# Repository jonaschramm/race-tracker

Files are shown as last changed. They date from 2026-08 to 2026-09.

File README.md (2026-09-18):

<p align="center">
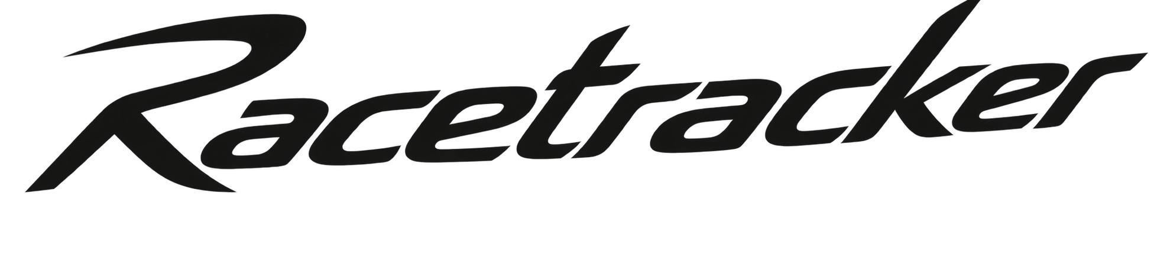
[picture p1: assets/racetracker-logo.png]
RaceTracker
  
</p>

Custom PCB data logger for motorcycle racing: GPS position + IMU motion data,
logged to a microSD card, with an e-Paper status display. Built around an
ESP32-S3 (WiFi/BT built in) so it can also stream/sync over WiFi.

## Current version: V3 (ESP32-S3)

**This is the active, current board.** Everything else in this repo (see
[History / older versions](#history--older-versions) below) is superseded —
kept for reference only, not under active development.

```
RaceTracker.kicad_prj/V3 ESP32/RaceTracker_v3/RaceTracker_v3.kicad_pro
```

Open that project file in KiCad (10.0.5 or newer) — schematic
(`RaceTracker_v3.kicad_sch`) and PCB (`RaceTracker_v3.kicad_pcb`) are
alongside it.

### Status

- Schematic: ERC clean (0 violations).
- PCB: fully routed by hand, `kicad-cli pcb drc --severity-all` → 0 errors
  (a handful of expected warnings only — see below).
- Board: 4-layer, ~56×66mm with rounded corner bosses for 4× M2 mounting
  holes.
- BOM: all 44 parts have a manufacturer part number and LCSC code (or
  DigiKey, where LCSC doesn't carry the part) in the schematic symbol
  properties — see `bom/bom.csv`.

**Known, expected DRC warnings (not bugs):**
- `lib_footprint_mismatch` on J1, J5, J6, SW1, U1 — these footprints were
  deliberately hand-adjusted to match real component pad geometry (pulled
  from the parts' own datasheets/reference designs) rather than the stock
  KiCad library footprint. **Do not run "Update Footprint from Library" on
  these** — it would silently overwrite the verified geometry.

### Key components

| Function | Part |
|---|---|
| MCU (WiFi + BT) | ESP32-S3-WROOM-1-N8 (U1) |
| IMU (6-axis) | Würth WSEN-ISDS (U4) |
| GPS | external module via J3 (2.54mm header, I2C) — no onboard GPS |
| Storage | microSD (J4) |
| Display | e-Paper via J6 (8-pin header) |
| Charging | MCP73831 Li-Ion charger (U2) + USB-C (J1) |
| 3.3V rail | AP2112K-3.3 LDO (U3) |
| Debug | UART via J5 (4-pin header) |

Pin-header connectors (J3, J5, J6) have their pin functions silkscreened
next to each pin so nothing gets miswired when the board is in hand without
the schematic open.

### 3D preview

<p align="center">
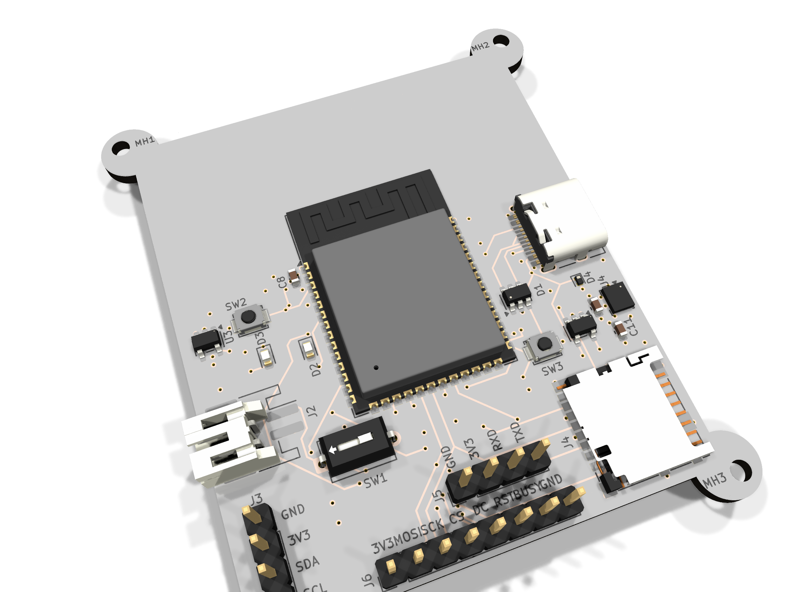
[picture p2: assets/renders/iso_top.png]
RaceTracker V3 - component side
  
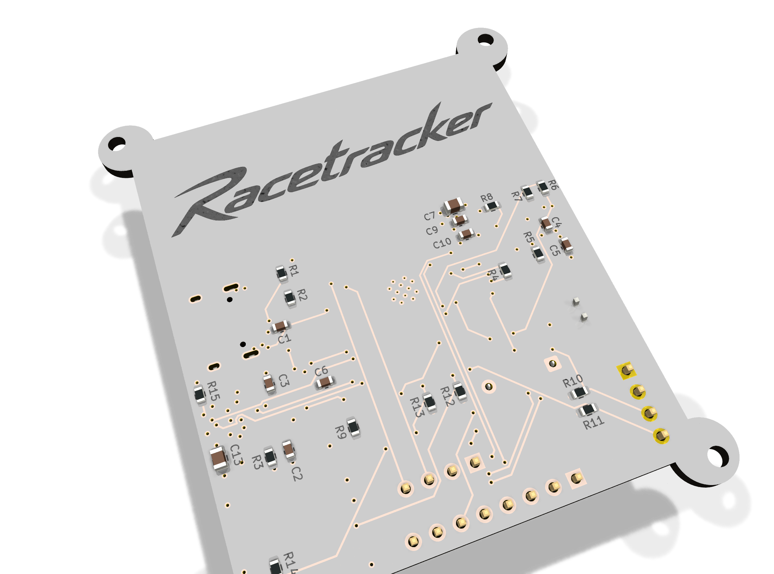
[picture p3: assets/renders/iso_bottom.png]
RaceTracker V3 - logo side
  
</p>

Rendered straight from the board file (`kicad-cli pcb render`). A ready-to-embed,
interactive 3D model (quantized GLB, 3.4 MB — Draco was tried first but needs an
external decoder that not every embedding context can reach) lives at
[`RaceTracker.kicad_prj/V3 ESP32/RaceTracker_v3/3d/RaceTracker_v3.glb`](RaceTracker.kicad_prj/V3%20ESP32/RaceTracker_v3/3d/RaceTracker_v3.glb) —
drop it into a [`<model-viewer>`](https://modelviewer.dev/) tag on any webpage to let
visitors spin the board around (also works in AR on phones). More stills in
`assets/renders/`.

### Open items

Not yet done — flagging so nothing is assumed finished:

1. **RF review** — the ESP32-S3's on-board antenna keepout is respected on
   the PCB, but nobody with hands-on RF experience has reviewed the
   placement. Espressif's own guideline calls for **≥15mm clearance between
   the antenna and any metal** (enclosure, shielding) — the two mounting
   holes closest to the antenna (top-left/top-right) are only ~3mm away, so
   **use nylon/plastic M2 screws there**, not metal.
2. **Enclosure / mechanical design** — no current mechanical spec for a
   case; board dimensions have changed several times, don't reuse an old one.
3. **3D models / "finished" 3D view** — not started.
4. Two BOM values are assumptions, not confirmed: D2/D3 LED colors (set to
   red/green — schematic didn't specify a color) and SW1's exact MPN
   (couldn't verify its physical dimensions against the datasheet).
5. 27 pads show as "no net" against the schematic's auto-generated
   placeholder nets — reviewed at a glance as genuinely-unused pins
   (GPIO headroom, USB SBU lines), not individually re-verified.

## Repo layout

```
RaceTracker.kicad_prj/
├── *.kicad_sch, RaceTracker.kicad_pcb   ← V1 (SAMD21 + onboard GPS/WiFi modules) — historical
├── V3 ESP32/RaceTracker_v3/             ← V3 (ESP32-S3) — CURRENT, see above
└── V3 ESP32/tools/                      ← pcbnew scripting helpers used while building V3
v2-simple/                                ← V2 (SAMD21, simplified, external GPS/WiFi) — abandoned mid-layout, superseded by V3
reference/eagle/                          ← imported Eagle symbols (Arduino MKR WiFi 1010) used as a source for V1/V2 parts
bom/bom.csv                               ← current BOM with MPN/LCSC/pricing data (V3)
```

### History / older versions

- **V1** (`RaceTracker.kicad_prj/*.kicad_sch` at the repo root, tag
  `v1-full`): original design — Arduino MKR WiFi 1010 (SAMD21) + separate
  u-blox ZED-F9P RTK GPS module + MPU-6050 IMU. Fully routed, but heavier
  and pricier than needed for the actual use case.
- **V2 / `v2-simple`**: a pivot to drop the onboard GPS/WiFi modules in
  favor of external pluggable headers, still on the SAMD21. Placement-only;
  routing was never finished before the project moved to V3's ESP32-S3
  (which has WiFi/BT built in, removing the need for a separate radio
  module entirely). Kept for reference; not maintained.

## Branches

`main` tracks the current state (V3). Historical exploration happened on
`v2-simple` — merged into `main` and not separately maintained going forward.

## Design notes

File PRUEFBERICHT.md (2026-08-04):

# Prüfbericht zur Handvalidierung — Race Tracker Platine

Erzeugt aus denselben Daten wie die Schaltpläne. Zweck: du kannst jede Verbindung gegen die
Original-Referenzschaltpläne (Arduino MKR WiFi 1010 / SparkFun GPS-RTK-SMA) abhaken,
ohne die KiCad-Datei lesen zu müssen.

**So prüfst du:** Für jedes Netz unten steht, welche Bauteil-Pins zusammenhängen.
Die Spalte *Quelle* sagt, ob das exakt so im Referenz-Schaltplan steht.

## Blatt: Power

Bauteile auf diesem Blatt: **40**, Netze: **30**

| Netz | verbundene Bauteil-Pins | Quelle |
|---|---|---|
| `+3V3` | R24.1, R26.1, U6.OUT | identisch |
| `+3V3D` | U3.OUT, C8.1, C9.2, C33.1 | identisch |
| `+3V8` | U5.SYS, L2.2, C19.1, C20.1, C22.1, C32.1, R23.2, U3.EN, U3.IN, U6.EN, U6.IN | identisch |
| `+5V` | D1.4, F1.2, Q2.D, D3.C | identisch |
| `BATT_RAW` | J7.1, F2.1 | = `N$3` |
| `CC1` | R37.1 ⚠️ **nur 1 Anschluss** | manuell (Neuentwurf, s.u.) |
| `CC2` | R38.1 ⚠️ **nur 1 Anschluss** | manuell (Neuentwurf, s.u.) |
| `CHG_BOOT` | U5.BTST, C15.1 | = `N$18` |
| `CHG_CE` | U5.CE, R25.2 | = `N$24` |
| `CHG_ILIM` | U5.ILIM, R28.1 | = `N$19` |
| `CHG_OTG` | U5.OTG, R26.2, Q3.D | = `N$22` |
| `CHG_REGN` | U5.REGN, C16.1, R30.1 | = `N$21` |
| `CHG_SW` | U5.SW, L2.1, C15.2 | = `N$15` |
| `CHG_TS` | U5.TS1, U5.TS2, R29.2, R30.2 | = `N$23` |
| `CHG_VBUS` | Q2.S, Q2.C, R27.2, U5.VBUS, C14.1 | = `N$17` |
| `DL2_ANODE` | R23.1, DL2.A | = `N17798864` |
| `DL3_ANODE` | R27.1, DL3.A | = `N17834267` |
| `GND` | R37.2, R38.2, R1.1, C1.2, J7.2, J7.SH, D2.A, DL3.C, U5.PGND, U5.TH, C12.2, C13.2, C14.2, C16.2, C19.2, C20.2, C22.2, C32.2, R28.2, R29.1, R25.1, R1… | manuell (Neuentwurf, s.u.) |
| `I2C_SCL` | U5.SCL ⚠️ **nur 1 Anschluss** | = `PA09_S0_I2C_SCL` |
| `I2C_SDA` | U5.SDA ⚠️ **nur 1 Anschluss** | = `PA08_S0_I2C_SDA` |
| `PA18_OTG` | Q3.G ⚠️ **nur 1 Anschluss** | identisch |
| `PMICINT` | U5.INT, R24.2 | identisch |
| `STAT` | U5.STAT, DL2.C | identisch |
| `USB_N` | D1.3 ⚠️ **nur 1 Anschluss** | identisch |
| `USB_P` | D1.2 ⚠️ **nur 1 Anschluss** | identisch |
| `USB_SHIELD_RC` | D1.1, R1.2, C1.1 | = `N$1` |
| `VBAT` | F2.2, D2.C, U5.BAT | = `VBATT` |
| `VBUS_RAW` | F1.1 ⚠️ **nur 1 Anschluss** | = `N$2` |
| `VIN` | Q2.G, Q2.A, R19.2 | identisch |
| `VUSB1` | D3.A, U5.PMID, C12.1, C13.1 | identisch |

**Netze mit nur einem Anschluss auf Power** (8): `CC1`, `CC2`, `I2C_SCL`, `I2C_SDA`, `PA18_OTG`, `USB_N`, `USB_P`, `VBUS_RAW`

Das sind ungenutzte Pins (im Original gingen sie nur zu Steckverbindern, die wir weggelassen haben).
Sie sind **kein Fehler**, aber die ERC wird sie als „nicht verbunden“ melden — dort kannst du sie
mit einem No-Connect-Kreuz quittieren oder für spätere Erweiterungen offenlassen.

## Blatt: MCU_Radio

Bauteile auf diesem Blatt: **46**, Netze: **64**

| Netz | verbundene Bauteil-Pins | Quelle |
|---|---|---|
| `+3V3` | U1.VDDIN, U1.VDDIO@1, U1.VDDIO@2, C17.1, C18.1, C21.1, C24.1, C26.1, L3.1, R5.2, R21.1, R13.2, R14.2, R4.2, R15.1 | identisch |
| `+3V3D` | U2.VCC, U2.VCCIO, R7.2 | identisch |
| `DL1_ANODE` | R15.2, DL1.A | = `N$7` |
| `DL1_KATHODE` | Q1.D, DL1.C | = `N$10` |
| `EPD_BUSY` | U1.PA02 ⚠️ **nur 1 Anschluss** | = `PA02_AIN0` |
| `EPD_CS` | U1.PA06 ⚠️ **nur 1 Anschluss** | = `PA06_AIN6` |
| `EPD_DC` | U1.PA05 ⚠️ **nur 1 Anschluss** | = `PA05_AIN5` |
| `EPD_RST` | U1.PA04 ⚠️ **nur 1 Anschluss** | = `PA04_AIN4` |
| `GND` | U1.EP, U1.GND@1, U1.GND@2, U1.GND@3, U1.GNDANA, C17.2, C18.2, C21.2, C24.2, C26.2, C25.2, C23.2, C27.2, C5.2, C7.2, C6.2, R9.1, C3.1, C4.1, PB1.1, … | identisch |
| `I2C_SCL` | U1.PA09, R20.2, R13.1 | = `PA09_S0_I2C_SCL` |
| `I2C_SDA` | U1.PA08, R18.2, R14.1 | = `PA08_S0_I2C_SDA` |
| `IMU_INT` | U1.PB10 ⚠️ **nur 1 Anschluss** | = `PB10_TCC0-W4` |
| `LED_BLUE` | U2.RMII_RXD1/DAC17/GPIO26, DL4.RED_A | identisch |
| `LED_ERR` | U1.PA23 ⚠️ **nur 1 Anschluss** | = `PA23_TC4-W1` |
| `LED_FIX` | U1.PA21 ⚠️ **nur 1 Anschluss** | = `PA21_TCC0-W7` |
| `LED_GREEN` | U2.RMII_RXD0/DAC16/GPIO25, DL4.GREEN_A | identisch |
| `LED_REC` | U1.PA22 ⚠️ **nur 1 Anschluss** | = `PA22_TC4-W0` |
| `LED_RED` | U2.RMII_CRSDV/GPIO27, DL4.BLUE_A | identisch |
| `NINA_GPIO13` | U2.JTCLK/GPIO13, R18.1 | = `N$11` |
| `NINA_GPIO14` | U2.JTMS/GPIO14, R20.1 | = `N$12` |
| `NINA_GPIO15` | U2.JTDO/GPIO15, R22.2 | = `N$26` |
| `NINA_GPIO21` | U2.SPIV_HD/RMII_TXEN/GPIO21, R12.2 | = `N$27` |
| `NINA_GPIO4` | U2.RMII_MDIO/GPIO4, R17.1 | = `N$13` |
| `NINA_LPO` | U2.LPO_IN/GPIO32 ⚠️ **nur 1 Anschluss** | = `N$25` |
| `NINA_RESET_N` | U2.RESET_N, R7.1, Q5.D | = `N$9` |
| `NINA_SELFRST` | R11.1, R17.2, Q5.G | = `N$28` |
| `PA00_XIN32` | U1.PA00/XIN32, Y1.2, C3.2 | identisch |
| `PA01_XOUT32` | U1.PA01/XOUT32, Y1.1, C4.2 | identisch |
| `PA03_VREFA` | U1.PA03, C5.1, C7.1 | identisch |
| `PA10_TCC0-W2` | U1.PA10 ⚠️ **nur 1 Anschluss** | identisch |
| `PA11_TCC0-W3` | U1.PA11 ⚠️ **nur 1 Anschluss** | identisch |
| `PA12_S2_TX/MOSI` | U1.PA12, U2.GPIO12 | identisch |
| `PA13_S2_RX/MISO` | U1.PA13, U2.SPIV_DI/GPIO23 | identisch |
| `PA14_S2_RTS/CS` | U1.PA14, U2.SPIV_CS/GPIO5, U2.UART_CTS/RMII_TXD0/SPIV_D0/GPIO19 | identisch |
| `PA15_S2_CTS/SCK` | U1.PA15, U2.SPIV_CLK/GPIO18, U2.UART_RTS/RMII_TXD1/SPIV_WP/GPIO22 | identisch |
| `PA18_OTG` | U1.PA18, R21.2 | identisch |
| `PA20_TCC0-W6` | U1.PA20, R16.2, Q1.G | identisch |
| `PA27_GPIO0` | U1.PA27, U2.RMII_CLK/GPIO0 | identisch |
| `PA28_ACK` | U1.PA28, U2.GPIO33 | identisch |
| `PA30_SWCLK` | U1.PA30/SWCLK, R4.1, R12.1 | identisch |
| `PA31_SWDIO` | U1.PA31/SWDIO, R22.1 | identisch |
| `PB02_AIN10` | U1.PB02 ⚠️ **nur 1 Anschluss** | identisch |
| `PB03_AIN11` | U1.PB03 ⚠️ **nur 1 Anschluss** | identisch |
| `PB08_RST` | U1.PB08, R10.1, Q5.G | identisch |
| `PB09_FILT` | U1.PB09, C6.1, R8.1, R9.2 | = `N$6` |
| `PB22_S5_TX` | U1.PB22, U2.UART_RXD/GPIO3 | identisch |
| `PB23_S5_RX` | U1.PB23, U2.UART_TXD/GPIO1 | identisch |
| `RESET#` | R6.2, Q5.D | identisch |
| `RESETN` | U1.RESETN, R2.2, R3.2, R6.1, R5.1, C2.1 | identisch |
| `RESETN_TP` | R2.1 ⚠️ **nur 1 Anschluss** | = `N$4` |
| `RESET_BTN` | PB1.2, R3.1 | = `N17658775` |
| `RGB_KATH1` | DL4.RED_C, R34.2 | = `N$14` |
| `RGB_KATH2` | DL4.GREEN_C, R35.2 | = `N$16` |
| `RGB_KATH3` | DL4.BLUE_C, R36.2 | = `N$20` |
| `SD_CD` | U1.PB11 ⚠️ **nur 1 Anschluss** | = `PB11_TCC0-W5` |
| `SD_CS` | U1.PA07 ⚠️ **nur 1 Anschluss** | = `PA07_AIN7` |
| `SPI_MISO` | U1.PA19 ⚠️ **nur 1 Anschluss** | = `PA19_S1_MISO` |
| `SPI_MOSI` | U1.PA16 ⚠️ **nur 1 Anschluss** | = `PA16_S1_MOSI` |
| `SPI_SCK` | U1.PA17 ⚠️ **nur 1 Anschluss** | = `PA17_S1_SCK` |
| `USB_N` | U1.PA24/USB_DM ⚠️ **nur 1 Anschluss** | identisch |
| `USB_P` | U1.PA25/USB_DP ⚠️ **nur 1 Anschluss** | identisch |
| `VBAT` | R8.2 | = `VBATT` |
| `VDDANA_FILT` | U1.VDDANA, L3.2, C23.1, C27.1 | = `N17852357` |
| `VDDCORE_DEC` | U1.VDDCORE, C25.1 | = `N17852431` |

**Netze mit nur einem Anschluss auf MCU_Radio** (21): `EPD_BUSY`, `EPD_CS`, `EPD_DC`, `EPD_RST`, `IMU_INT`, `LED_ERR`, `LED_FIX`, `LED_REC`, `NINA_LPO`, `PA10_TCC0-W2`, `PA11_TCC0-W3`, `PB02_AIN10`, `PB03_AIN11`, `RESETN_TP`, `SD_CD`, `SD_CS`, `SPI_MISO`, `SPI_MOSI`, `SPI_SCK`, `USB_N`, `USB_P`

Das sind ungenutzte Pins (im Original gingen sie nur zu Steckverbindern, die wir weggelassen haben).
Sie sind **kein Fehler**, aber die ERC wird sie als „nicht verbunden“ melden — dort kannst du sie
mit einem No-Connect-Kreuz quittieren oder für spätere Erweiterungen offenlassen.

## Blatt: GPS

Bauteile auf diesem Blatt: **23**, Netze: **28**

| Netz | verbundene Bauteil-Pins | Quelle |
|---|---|---|
| `+3V3` | U3.VCC, U3.V_USB, C4.1, C5.2, C7.2, D2.A, R7.2, R8.2 | manuell (Neuentwurf, s.u.) |
| `D1_ANODE` | R11.1, D1.A | = `N$2` |
| `D3_ANODE` | R12.1, D3.A | = `N$1` |
| `D4_ANODE` | R13.1, D4.A | = `N$7` |
| `D_SEL` | U3.D_SEL ⚠️ **nur 1 Anschluss** | identisch |
| `GEO_LED_D` | R25.2, R13.2 | zusammengeführt: `FENCE_STAT`, `N$9` |
| `GND` | U3.GND, C4.2, C5.1, C7.1, C1.2, E1.GND, B1.-, C3.2, D1.C, D3.C, D4.C | identisch |
| `GPS_ANT_BIAS` | R14.1, FB1.2, C1.1 | = `ANT_VCC` |
| `GPS_GEO_STAT` | U3.GEO_STAT, R25.1 | = `N$20` |
| `GPS_PPS` | U3.TIMEPULSE, R21.1 | zusammengeführt: `N$21`, `PPS` |
| `GPS_RF` | U3.RF_IN, FB1.1, E1.SIGNAL | = `GPS_ANT1` |
| `GPS_RTK_STAT` | U3.RTK_STAT, R24.1 | = `N$19` |
| `GPS_TX2` | U3.TX2 ⚠️ **nur 1 Anschluss** | = `TX2_P` |
| `GPS_VBCKP` | U3.V_BKCP, B1.+, C3.1, R5.1 | = `BACKUP` |
| `I2C_SCL` | U3.SCL/CLK, R7.1 | manuell (Neuentwurf, s.u.) |
| `I2C_SDA` | U3.SDA/!CS!, R8.1 | manuell (Neuentwurf, s.u.) |
| `N$11` | U3.USB_D+ ⚠️ **nur 1 Anschluss** | identisch |
| `N$12` | U3.USB_D- ⚠️ **nur 1 Anschluss** | identisch |
| `N$13` | U3.V_RF, R14.2 | identisch |
| `N$14` | U3.RX2 ⚠️ **nur 1 Anschluss** | identisch |
| `N$15` | U3.EXTINT ⚠️ **nur 1 Anschluss** | identisch |
| `N$16` | U3.!RESET! ⚠️ **nur 1 Anschluss** | identisch |
| `N$18` | U3.!SAFEBOOT! ⚠️ **nur 1 Anschluss** | identisch |
| `N$6` | R5.2, D2.C | identisch |
| `PPS_LED_D` | R21.2, R11.2 | zusammengeführt: `N$4`, `PPS_STAT` |
| `RTK_LED_D` | R24.2, R12.2 | zusammengeführt: `N$3`, `RTK_STAT` |
| `RXLV` | U3.RX/MOSI ⚠️ **nur 1 Anschluss** | identisch |
| `TXLV` | U3.TX/MISO ⚠️ **nur 1 Anschluss** | identisch |

**Netze mit nur einem Anschluss auf GPS** (10): `D_SEL`, `GPS_TX2`, `N$11`, `N$12`, `N$14`, `N$15`, `N$16`, `N$18`, `RXLV`, `TXLV`

Das sind ungenutzte Pins (im Original gingen sie nur zu Steckverbindern, die wir weggelassen haben).
Sie sind **kein Fehler**, aber die ERC wird sie als „nicht verbunden“ melden — dort kannst du sie
mit einem No-Connect-Kreuz quittieren oder für spätere Erweiterungen offenlassen.

## Bewusst weggelassene Bauteile der Referenzdesigns

| Referenz | Bauteil | Warum weggelassen |
|---|---|---|
| MKR1010 | J2, J3, J4, J5 | MKR-Formfaktor-Steckleisten; wir verdrahten direkt statt über Header |
| MKR1010 | U4 (ECC508A) | Crypto-Chip laut deiner Entscheidung weggelassen (später als I2C-Chip nachrüstbar) |
| MKR1010 | R31, R32 | 0R-Jumper, die nur zur entfallenen Steckleiste J5 führten (tote Stummel) |
| MKR1010 | C28–C31 | im Original bereits als DNP (unbestückt) markiert |
| GPS-RTK | J5 (USB-C), U2 (LDO) | doppelt vorhanden — unser Board hat eigene USB-C-Buchse und eigene 3V3-Versorgung |
| GPS-RTK | J1–J4, J6, J7 | Qwiic-/Serial-/Debug-Stecker; nicht nötig bei Direktverdrahtung |
| GPS-RTK | R2,R3,R4,R6,R9,R10 | 33Ω-Serienwiderstände, die im Original nur zu diesen Steckern führten |
| GPS-RTK | E2 | zweite SMA-Buchse (externer Timepulse-Ausgang); du wolltest eine einzelne Antenne |
| GPS-RTK | D6 | ESD-Schutz für das entfallene eigene USB des SparkFun-Boards |
| GPS-RTK | Lötjumper PPS, PPS_LED, RTK, FENCE, JP5, PWR, SPI | siehe Warnung unten |

## ⚠️ Wichtig: korrigierter Fehler aus der Vorversion

In der vorherigen Version waren die drei GPS-Status-LEDs (PPS, RTK-Fix, Geofence) **elektrisch tot**.
Ursache: Im SparkFun-Original sitzen in jeder LED-Kette Lötjumper (standardmäßig geschlossene,
auftrennbare Kupferbrücken). Ich hatte diese Bauteile weggelassen — damit war die Kette an zwei
Stellen offen, das Signal vom ZED-F9P erreichte die LED nie.

Jetzt behoben: die Netze beidseits jedes entfernten Jumpers wurden zusammengeführt
(z. B. `PPS_STAT` + `N$4` → `PPS_LED_D`), was dem geschlossenen Jumper elektrisch entspricht.
**Bitte gegenprüfen:** ZED-F9P `TIMEPULSE` → R21 → R11 → D1 → GND (analog RTK_STAT→R24→R12→D3,
GEO_STAT→R25→R13→D4).

## Was noch offen ist

1. ~~**Sensors_Storage-Blatt** fehlt~~ ✓ erledigt — MPU-6050 (U7), MicroSD (J11), e-Paper-Stecker (J10), 3× Status-LEDs (DL10–12) vorhanden
2. ~~**SWD-Programmierheader** fehlt~~ ✓ erledigt — CONN_SWD_1x5 in MCU_Radio.kicad_sch
3. **USB-C-Footprint** ist noch Platzhalter (`TBD_USBC_CONNECTOR`) — braucht ein konkretes Bauteil
4. **Footprints zuweisen** — Großteil der Passiven (R, C, D, L) und einige Stecker haben noch kein Footprint im Schaltplan-Instanz
5. **ERC** in KiCad noch nicht gelaufen
6. **PCB-Layout**: erst nach ERC und vollständiger Footprint-Zuweisung sinnvoll

## Automatische Verbindungsprüfung

Prüft für jeden Bauteil-Pin: hat er im Original ein Netz — und ist dieses Netz im Schaltplan
auch tatsächlich zugeordnet? (Diese Prüfung deckte auf, dass alle LEDs und Dioden unverbunden
waren, weil meine Symbole `1`/`2` als Pad-Namen benutzten, die Quellen aber `A`/`C`.)

**Ergebnis: 0 Fehler.** Jeder Pin, der in der Quelle ein Netz hat, ist zugeordnet.

12 Pins sind ohne Netz — **auch im Original unbeschaltet**, also kein Fehler:

| Blatt | Bauteil | unbeschaltete Pins |
|---|---|---|
| GPS | U3 | ANT_DETECT, ANT_OFF, !ANT_SHORT!, TX_READY |
| MCU_Radio | U2 | ADC2/GPIO34, ADC3/GPIO39, ADC4/GPIO36, ANT, RMII_MDCLK/GPIO2, ADC34/GPI35 |
| Power | U5 | D+, D- |

Die ERC wird diese Pins als „nicht verbunden“ melden. Das ist erwartet — im KiCad-Schaltplan
kannst du sie mit einem No-Connect-Kreuz quittieren oder für Erweiterungen offenlassen.

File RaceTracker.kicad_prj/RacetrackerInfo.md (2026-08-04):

# Race Tracker Platine — Projektkontext

> Diese Datei ist das **Projektgedächtnis**. Claude Code liest sie automatisch beim Start
> in diesem Verzeichnis. Sie ersetzt den Chatverlauf von claude.ai, der sich nicht
> übertragen lässt.

**Autor:** Jona Schramm · Objectix Software Solutions

## Was das Projekt ist

Eigene 4-Lagen-Platine: GPS/IMU-Datenlogger für den Renneinsatz auf einem Motorrad.
Ersetzt einen Breadboard-Prototyp (Arduino MKR WiFi 1010 + SparkFun GPS-RTK-SMA +
MPU-6050 + MicroSD + Waveshare e-Paper) durch ein integriertes Custom-Board.

**Stand (2026-08-04):** Alle 4 Schaltplan-Blätter fertig. SWD-Header vorhanden. ERC noch nicht gelaufen. Footprints für viele Passive fehlen. PCB-Layout noch nicht begonnen.

## Grundprinzip: ableiten, nicht erfinden

Kritische Chips werden **nicht neu entworfen**, sondern aus offengelegten
Referenz-Schaltplänen übernommen. Keine erfundenen Bauteilwerte oder Pin-Zuordnungen.

| Blatt | Quelle | Status |
|---|---|---|
| Power | `MKRWiFi1010V2_0.sch` (EAGLE) | aus Referenz abgeleitet ✓ |
| MCU_Radio | `MKRWiFi1010V2_0.sch` (EAGLE) | aus Referenz abgeleitet ✓ |
| GPS | `Qwiic_GPS-RTK-SMA_-_ublox_ZED-F9P.sch` (EAGLE) | aus Referenz abgeleitet ✓ |
| Sensors_Storage | **keine Referenzdatei** | ⚠️ aus Datenblättern, ungeprüft |

**Die EAGLE-Quelldateien fehlen in diesem Repo** (Lizenz/Größe). Lade sie nach:
- Arduino: https://content.arduino.cc/assets/MKRWiFi1010-reference.zip
- SparkFun: https://github.com/sparkfun/Qwiic_GPS-RTK2 (Branch `Add-SMA`, Ordner `Hardware/`)

Ablage: `reference/eagle/`. Die daraus extrahierten Netzlisten liegen bereits
als JSON in `reference/extract/` und `reference/extract_gps/` — damit läuft der
Generator auch ohne die Originaldateien.

## Wie das hier funktioniert

Die `.kicad_sch`-Dateien werden **vollständig generiert**. Von Hand editieren lohnt
nicht — beim nächsten Lauf ist es weg. Änderungen gehören in die Skripte.

```bash
cd tools
python3 build_lib_v2.py        # Symbolbibliothek (Pin-Stapelung, Power-Symbole)
python3 build_sensors_lib.py   # zusätzliche Symbole für Sensors_Storage + SWD
python3 build_footprints.py    # Footprints aus den EAGLE-.brd-Dateien
python3 build_v2.py            # alle 4 Schaltplan-Blätter
python3 build_report.py        # Prüfbericht
```

Prüfwerkzeuge (nach jedem Lauf ausführen):

```bash
python3 final_check.py       # Netze: zerfallen / kurzgeschlossen  -> muss 0/0 sein
python3 verify_output.py     # offene Pins, lose Drahtenden
python3 check_connections.py # Symbol-Pads gegen Quelldatei
```

### Architektur der Skripte

| Datei | Aufgabe |
|---|---|
| `gen_symbols_v2.py` | Symbol-Bausteine, Pin-Typ-Logik, Pin-Stapelung, Power-Symbole |
| `build_lib_v2.py` | erzeugt `RaceTracker.kicad_sym` aus den Referenz-Netzlisten |
| `build_sensors_lib.py` | MPU-6050, MicroSD, e-Paper, SWD-Header (nicht referenzbasiert!) |
| `sheet_v3.py` | **Layout-Engine**: Platzierung, Sammelschienen, Routing, Knotenpunkte |
| `build_v2.py` | Netz-Umbenennungen + welches Bauteil auf welches Blatt |
| `netcheck.py` | rekonstruiert Netze geometrisch aus der fertigen Datei (KiCad-Logik) |

## Hart erkaufte Erkenntnisse — bitte nicht rückgängig machen

Diese Punkte haben je mehrere ERC-Runden gekostet:

1. **Pin-Stapelung.** Der ZED-F9P hat 56 GND-Pads auf einem logischen Pin. Ohne
   Stapelung entstehen 56 Labels und der Plan ist unlesbar. Versteckte Duplikate
   müssen `passive` sein, nicht `power_in` — sonst legt KiCad implizite Netze an.
2. **Pad-Namen aus der Quelle übernehmen.** Dioden/LEDs heißen dort `A`/`C`, nicht `1`/`2`;
   die GPS-Ferritperle `P1`/`P2`; der Taster PTS820 hat die Schaltkontakte auf Pad **5/6**
   (1–4 ist nur Gehäusemasse). Passt das nicht, ist das Bauteil **stumm unverbunden**.
3. **Knotenpunkte nur innerhalb desselben Netzes.** Ein Knoten verbindet alles, was dort
   liegt — netzübergreifend gesetzt erzeugt er Kurzschlüsse.
4. **T-Verbindungen brauchen einen Knotenpunkt.** Endet ein Draht mitten auf einem anderen,
   wertet KiCad das ohne Knoten nicht als Verbindung.
5. **Duplikate nur innerhalb desselben Netzes entfernen.** Sonst löscht ein Netz das
   Drahtstück eines anderen, das zufällig gleich liegt.
6. **Labels sitzen direkt am Pin, ohne Stichleitung.** Jede Stichleitung kann ein fremdes
   Netz berühren. Überdeckende Beschriftungen sind kosmetisch, ein Kurzschluss nicht.
7. **Referenzen projektweit eindeutig.** Beide Referenzentwürfe nummerieren ab 1 —
   GPS-Bauteile liegen deshalb im 100er-Bereich (`U103`, `R114`).
8. **Alles auf 1,27 mm-Raster.** Off-Grid-Punkte sind die klassische Ursache für
   „sieht verbunden aus, ist es aber nicht".
9. **PWR_FLAG-Merker pro Layout-Versuch zurücksetzen.** Das Papierformat wird durch
   Probieren bestimmt; ein verworfener Versuch darf die Flags nicht verbrauchen.

## Bewusste Entscheidungen

- **USB-C statt Micro-USB** (Referenz hat Micro-USB), CC1/CC2-Pulldowns R37/R38 je 5,1 kΩ
- **Zwei 3V3-Schienen**: `+3V3` (SAMD21 + Rest), `+3V3D` (nur NINA-W102, Rauschisolierung)
- **ECC508A weggelassen** — später als I2C-Chip nachrüstbar
- **Lötjumper der Referenzen weggelassen**, Netze beidseits zusammengeführt
  (ohne das wären die GPS-Status-LEDs elektrisch tot)
- **SparkFun-Redundanz weggelassen**: eigener USB-C, eigener LDO, Qwiic-Stecker
- **e-Paper steckbar** (8-polig), nicht fest verlötet
- **No-Connect-Kreuze** auf allen bewusst freien Pins — willst du einen nutzen, Kreuz löschen

## Bus-Belegung

- **I2C** `I2C_SDA`/`I2C_SCL`: ZED-F9P 0x42, MPU-6050 0x68, BQ24195L 0x6B — kein Konflikt
- **SPI** `SPI_MOSI`(PA16)/`SPI_SCK`(PA17)/`SPI_MISO`(PA19): MicroSD + e-Paper
- **CS/Steuerung**: `SD_CS`(PA07), `SD_CD`(PB11), `EPD_CS`(PA06), `EPD_DC`(PA05),
  `EPD_RST`(PA04), `EPD_BUSY`(PA02), `IMU_INT`(PB10)
- **Status-LEDs**: `LED_FIX`(PA21), `LED_REC`(PA22), `LED_ERR`(PA23)

⚠️ Die CS-/Steuerpins habe **ich** frei gewählt. Wenn die Prototyp-Firmware feste Pins
hat, hier anpassen statt die Firmware umzuschreiben.

## Offene Punkte

1. **USB-C-Footprint** ist Platzhalter (`TBD_USBC_CONNECTOR`) — braucht eine konkrete Teilenummer (z. B. JLCPCB-Nummer oder Datenblatt-MPN).
2. **ERC in KiCad ausführen** — Bericht als `.rpt` speichern und in Repo einchecken. Vorher Annotation (nur unbeschriftete Symbole) und PWR_FLAGs ergänzen.
3. **Footprints zuweisen** — Großteil der Passiven und einige Stecker haben noch leeres Footprint-Feld. Danach Netzliste erzeugen.
4. **Sensors_Storage gegen Datenblätter prüfen** (MPU-6050, MicroSD-Buchse, e-Paper-Stecker) — dieses Blatt ist nicht referenzbasiert und bisher ungeprüft.
5. **PCB-Layout**: 4 Lagen, Antennen-Keepouts um NINA-W102 und ZED-F9P nicht verhandelbar, abgewinkelte SMA-Buchse, M2/M2.5-Befestigungslöcher in den Ecken.
6. **Gegenprüfung durch eine Person mit KiCad-Erfahrung vor der Bestellung.**

Bereits erledigt (Stand 2026-08-04):
- ✓ Alle 4 Schaltplan-Blätter fertig (Power, MCU_Radio, GPS, Sensors_Storage)
- ✓ SWD-Programmierheader (CONN_SWD_1x5) in MCU_Radio vorhanden
- ✓ MPU-6050, MicroSD, e-Paper-Stecker, Status-LEDs in Sensors_Storage eingebaut

## Arbeitsweise

- KiCad-Version des Nutzers: **10.0.5**. Geschrieben wird Format `20231120` (KiCad 8) —
  KiCad liest ältere Formate und hebt sie beim Speichern an. Die Versionswarnung beim
  Öffnen ist erwartet, kein Fehler.
- **ERC ist der eigentliche Test.** Die Skripte prüfen nur, was jemand vorher bedacht hat.
  Nach jeder Änderung: in KiCad öffnen, ERC laufen lassen, Bericht auswerten.
- Beim Annotieren **nur unbeschriftete Symbole** wählen — sonst überschreibt KiCad die
  Bauteilnamen, die mit den Referenz-Schaltplänen und dem Prüfbericht übereinstimmen.

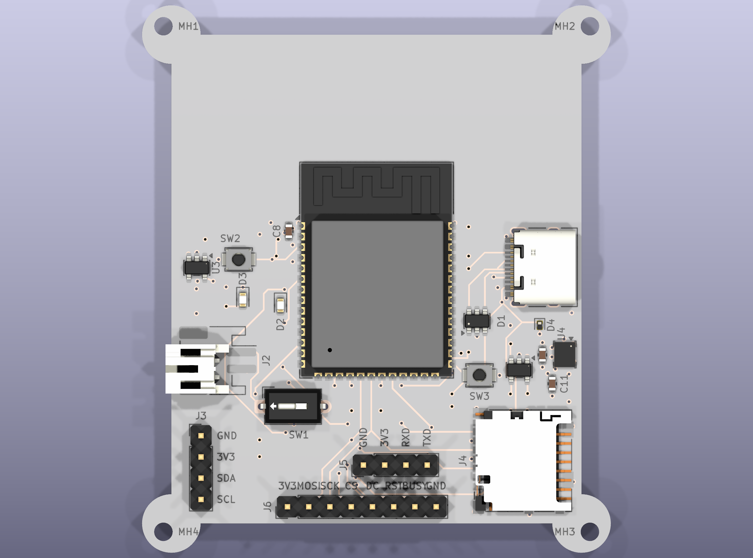
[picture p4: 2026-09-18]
assets/renders/top.png

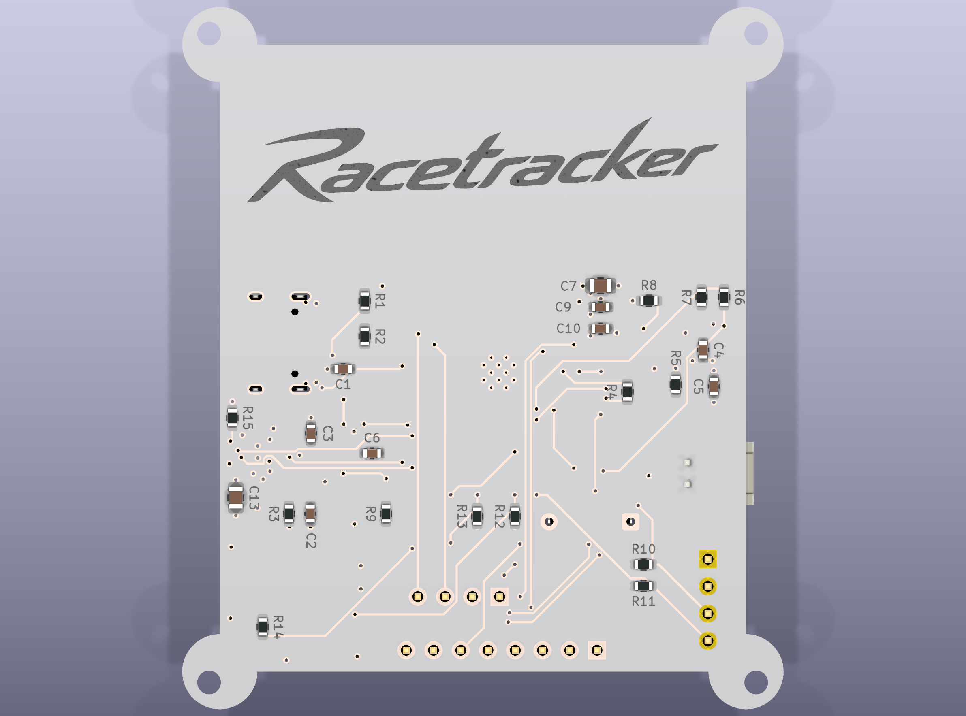
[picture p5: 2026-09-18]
assets/renders/bottom.png

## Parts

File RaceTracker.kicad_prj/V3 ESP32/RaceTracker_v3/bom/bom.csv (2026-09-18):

Reference | Qty | Value | Footprint | MPN | Manufacturer | LCSC | LC_Stock | Chosen_Distributor | Datasheet | Validated | DNP | Notes
C1,C4,C9,C5 | 4 | 1uF | 0603 | CL10A105KB8NNNC | Samsung Electro-Mechanics | C15849
C3,C2 | 2 | 4.7uF | 0603 | CL10A475KO8NNNC | Samsung Electro-Mechanics | C19666
C7 | 1 | 22uF | 0805 | CL21A226MAQNNNE | Samsung Electro-Mechanics | C45783
C12,C10,C11,C6,C8 | 5 | 100nF | 0603 | CC0603KRX7R9BB104 | Yageo | C14663
C13 | 1 | 10uF | 0805 | CL21A106KAYNNNE | Samsung Electro-Mechanics | C15850
D1 | 1 | USBLC6-2SC6 | SOT-23-6 | USBLC6-2SC6 | STMicroelectronics | C2687116
D2 | 1 | Charging | 0603 | XL-1608SURC-06 | XLSEMI (Chenzhixin) | C965799
D3 | 1 | Power | 0603 | XL-1608UGC-04 | XLSEMI (Chenzhixin) | C965804
D4 | 1 | PESD5V0S1UL | SOD-882 | PESD5V0S1UL | Nexperia | C85402
J1 | 1 | USB-C | USB_C_Receptacle_HRO_TYPE-C-31-M-12 | TYPE-C-31-M-12 | Korean Hroparts Elec | C165948
J2 | 1 | Battery | JST_PH_S2B-PH-SM4-TB_1x02-1MP_P2.00mm_Horizontal | S2B-PH-SM4-TB(LF)(SN) | JST | C295747
J3 | 1 | Qwiic GPS (I2C) | PinHeader_1x04_P2.54mm_Vertical | PZ254V-11-04P | BOOMELE | C2691448
J4 | 1 | microSD | microSD_HC_Molex_104031-0811 | 104031-0811 | Molex | C585350
J5 | 1 | UART Debug | PinHeader_1x04_P2.54mm_Vertical | PZ254V-11-04P | BOOMELE | C2691448
J6 | 1 | e-Paper (steckbar) 8p | PinHeader_1x08_P2.54mm_Vertical | PZ254V-11-08P | BOOMELE | C492407
R2,R1 | 2 | 5.1k | 0603 | 0603WAF5101T5E | Uniroyal Elec | C23186
R3 | 1 | 2k | 0603 | 0603WAF2001T5E | Uniroyal Elec | C22975
R5,R4 | 2 | 1k | 0603 | 0603WAF1001T5E | Uniroyal Elec | C21190
R7,R6 | 2 | 1M | 0603 | 0603WAF1004T5E | Uniroyal Elec | C22935
R9,R14,R15,R13,R12,R8 | 6 | 10k | 0603 | 0603WAF1002T5E | Uniroyal Elec | C25804
R10,R11 | 2 | 4.7k | 0603 | 0603WAF4701T5E | Uniroyal Elec | C23162
SW1 | 1 | PWR | SW_DIP_SPSTx01_Slide_6.7x4.1mm_W7.62mm_P2.54mm_LowProfile | DSWB01LHGET | DECIGN | C126888
SW2 | 1 | RESET | SW_SPST_B3U-1000P | B3U-1000P | Omron | C231329
SW3 | 1 | BOOT | SW_SPST_B3U-1000P | B3U-1000P | Omron | C231329
U1 | 1 | ESP32-S3-WROOM-1-N8 | ESP32-S3-WROOM-1 | ESP32-S3-WROOM-1-N8 | Espressif Systems | C2913198
U2 | 1 | MCP73831T-2ACI/OT | SOT-23-5 | MCP73831T-2ACI/OT | Microchip Technology | C424093
U3 | 1 | AP2112K-3.3 | SOT-23-5 | AP2112K-3.3TRG1 | Diodes Incorporated | C23380830
U4 | 1 | WSEN-ISDS | LGA-14_3x2.5mm_P0.5mm_LayoutBorder3x4y | 2536030320001 | Wuerth Elektronik |  |  |  | https://www.we-online.com/components/products/datasheet/2536030320001.pdf

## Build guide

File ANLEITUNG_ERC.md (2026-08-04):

# Anleitung: ERC durchführen und wie es weitergeht

## Teil 1 — Projekt öffnen

1. ZIP entpacken. Wichtig: **den kompletten Ordner** `RaceTracker.kicad_prj` behalten —
   die Bibliotheken werden über relative Pfade gefunden, einzelne Dateien allein funktionieren nicht.
2. `RaceTracker.kicad_pro` öffnen (nicht die `.kicad_sch` direkt).
3. KiCad meldet beim Öffnen, dass die Dateien von einer älteren Version stammen.
   **Das ist erwartet und kein Fehler** — KiCad 10 liest ältere Formate und hebt sie beim
   Speichern automatisch an. Umgekehrt ginge es nicht, deshalb schreibe ich bewusst das ältere Format.
4. Falls Symbole als rote Fragezeichen erscheinen: `Einstellungen → Symbolbibliotheken verwalten`
   → Reiter *Projektspezifische Bibliotheken* → Eintrag `RaceTracker` muss auf
   `${KIPRJMOD}/RaceTracker.kicad_sym` zeigen.

## Teil 2 — Annotation prüfen (vor der ERC)

Die Power-Symbole tragen `#PWR?` als Referenz und müssen einmal durchnummeriert werden:

1. `Werkzeuge → Schaltplan annotieren`
2. Bereich: *Gesamter Schaltplan*, Option: **nur unbeschriftete Symbole**
   (sonst werden meine Bauteilnamen R1, C12, U5 … überschrieben — die sollen bleiben,
   weil sie mit den Referenz-Schaltplänen und dem Prüfbericht übereinstimmen!)
3. `Annotation durchführen`

## Teil 3 — ERC laufen lassen

1. `Inspektieren → Electrical Rules Checker` (oder das Käfer-Symbol in der Werkzeugleiste)
2. Button **ERC ausführen**
3. Ergebnis speichern: Button **Bericht speichern…** → als `.rpt` oder `.txt`
4. **Diese Textdatei schick mir bitte.** Sie ist das mit Abstand nützlichste Feedback, weil
   sie exakt benennt, welches Netz und welcher Pin betroffen ist — Screenshots kann ich nur
   grob interpretieren.

### Was du in der ERC erwarten kannst (kein Grund zur Sorge)

| Meldung | Anzahl ca. | Warum sie kommt |
|---|---|---|
| *Pin nicht verbunden* | ~39 | Freie GPIOs und im Original unbeschaltete Pins (siehe Tabelle unten) |
| *Power-Pin nicht getrieben* | einige | Es fehlen noch PWR_FLAG-Symbole an den Einspeisepunkten |
| *Symbol hat keine Footprint-Zuordnung* | viele | Footprints sind teils noch nicht zugewiesen |

**PWR_FLAG ergänzen** (behebt „Power-Pin nicht getrieben"):
Setze je ein `PWR_FLAG`-Symbol an die Stelle, wo Energie ins Netz kommt —
also an `+5V` (am Ausgang der Sicherung F1), an `VBAT` (am Akkustecker J7) und
an `+3V3` / `+3V3D` (an den LDO-Ausgängen von U6 bzw. U3).

**No-Connect-Kreuze** (behebt „Pin nicht verbunden"):
Taste `Q` und dann auf die Pins klicken, die absichtlich frei bleiben sollen.
Bei den freien SAMD21-GPIOs würde ich das **nicht** machen — die brauchen wir noch
für das Sensors_Storage-Blatt.

## Teil 4 — Die 39 offenen Pins im Detail

Alle geprüft, keiner davon ist ein Fehler:

| Blatt | Bauteil | Pins | Einordnung |
|---|---|---|---|
| MCU_Radio | U1 (SAMD21) | 3, 9–12, 15, 16, 19, 20, 30–32, 47, 48 | **Freie GPIOs.** Gingen im MKR nur zu Steckleisten. Reserve für Sensors_Storage (CS-Leitungen, IMU-Interrupt) |
| MCU_Radio | U2 (NINA) | 2–5, 13, 25, 34 | ADC- und RMII-Pins, im Original ebenfalls unbeschaltet |
| GPS | U3 (ZED-F9P) | 4, 5, 6, 46 | ANT_DETECT, ANT_OFF, ANT_SHORT, TX_READY — im Original unbeschaltet |
| GPS | U3 | 26, 27, 39, 40, 42, 43, 47, 49, 50, 51 | UART2, USB, UART1, D_SEL, RESET, SAFEBOOT, EXTINT — gingen nur zu den entfallenen Steckern |
| Power | U5 (BQ24195L) | 2, 3 | USB-D+/D− des Ladereglers, im Original unbeschaltet |
| Power | J1 (USB-C) | SBU1, SBU2 | Seitenband-Pins, nur für Alt-Modes nötig — brauchen wir nicht |

**Wichtig zur Bewertung:** Bei `U3.42/43` (UART TX/RX des GPS) und `U3.49` (RESET) lohnt
die Überlegung, ob du sie doch an freie SAMD21-Pins führen willst. UART wäre ein zweiter
Datenpfad neben I2C, RESET erlaubt einen harten Neustart des GPS per Software.
Sag Bescheid, dann verdrahte ich sie.

## Teil 5 — Nächste Schritte, in dieser Reihenfolge

~~2. **SWD-Programmierheader ergänzen.**~~ ✓ erledigt — CONN_SWD_1x5 in MCU_Radio

~~4. **Sensors_Storage-Blatt**~~ ✓ erledigt — MPU-6050, MicroSD, e-Paper, Status-LEDs vorhanden

Offen:

1. **ERC-Textbericht** — KiCad öffnen, ERC laufen lassen, Bericht als Textdatei speichern und hier einchecken.
2. **USB-C-Bauteil festlegen.** Der Footprint ist noch Platzhalter (`TBD_USBC_CONNECTOR`).
   Mit einer JLCPCB-Teilenummer oder einem Datenblatt kann der echte Footprint ergänzt werden.
3. **Footprints allen Bauteilen zuweisen** (`Werkzeuge → Eigenschaften bearbeiten`), dann Netzliste erzeugen.
4. **Erst danach PCB-Layout.**

## Teil 6 — Wie du mir am besten Rückmeldung gibst

Nach Nützlichkeit sortiert:

1. **ERC-Bericht als Textdatei.** Eindeutig, vollständig, direkt abarbeitbar.
2. **Ein konkretes Beispiel statt einer Sammelaussage.** „D2 hat keine Verbindung"
   führt mich sofort zur Ursache; „manche hängen in der Luft" kostet mich erst eine
   Suchrunde. Dein Hinweis genau dieser Art hat diesmal den Pad-Namen-Fehler aufgedeckt.
3. **Screenshots mit sichtbarem Blattrand**, nicht nur Ausschnitte — daran war
   vorher die schlechte Flächennutzung überhaupt erst erkennbar.
4. **Sagen, was bereits gut ist.** Sonst laufe ich Gefahr, etwas Funktionierendes
   wieder umzubauen.

Ein ehrlicher Hinweis noch: Ich kann die Dateien nie selbst öffnen oder rendern.
Meine Prüfungen (Netzabgleich gegen die Quelle, Verbindungsprüfung, Kollisionsprüfung)
laufen automatisiert über die erzeugten Dateien und finden genau die Fehlerklassen,
die ich vorher bedacht habe. Die ERC findet Klassen, die ich strukturell nicht sehe.
Deshalb ist dein ERC-Lauf kein Formalismus, sondern der eigentliche Test.

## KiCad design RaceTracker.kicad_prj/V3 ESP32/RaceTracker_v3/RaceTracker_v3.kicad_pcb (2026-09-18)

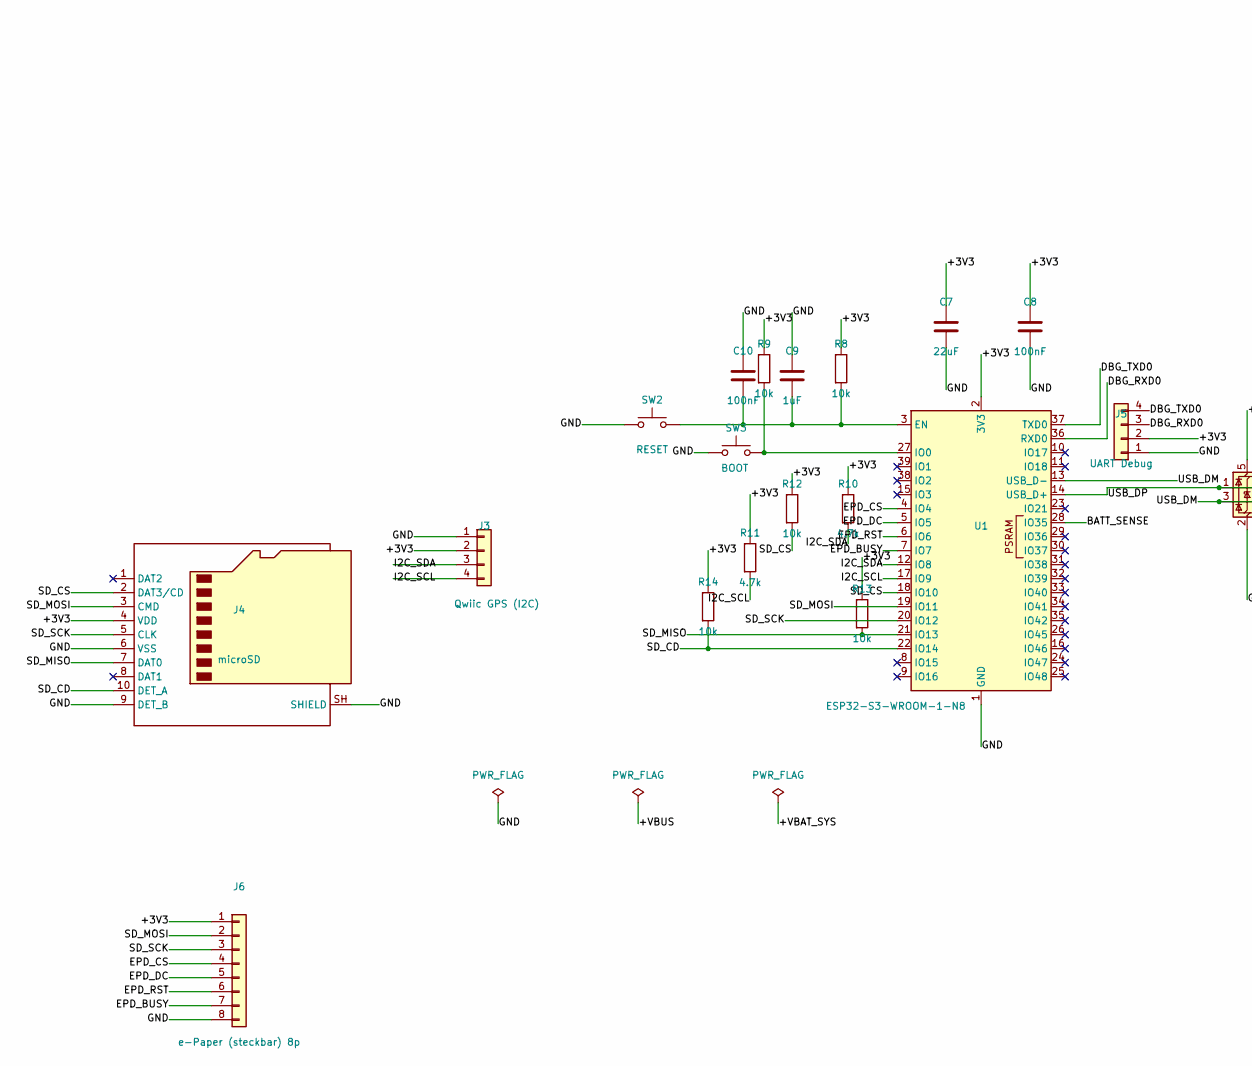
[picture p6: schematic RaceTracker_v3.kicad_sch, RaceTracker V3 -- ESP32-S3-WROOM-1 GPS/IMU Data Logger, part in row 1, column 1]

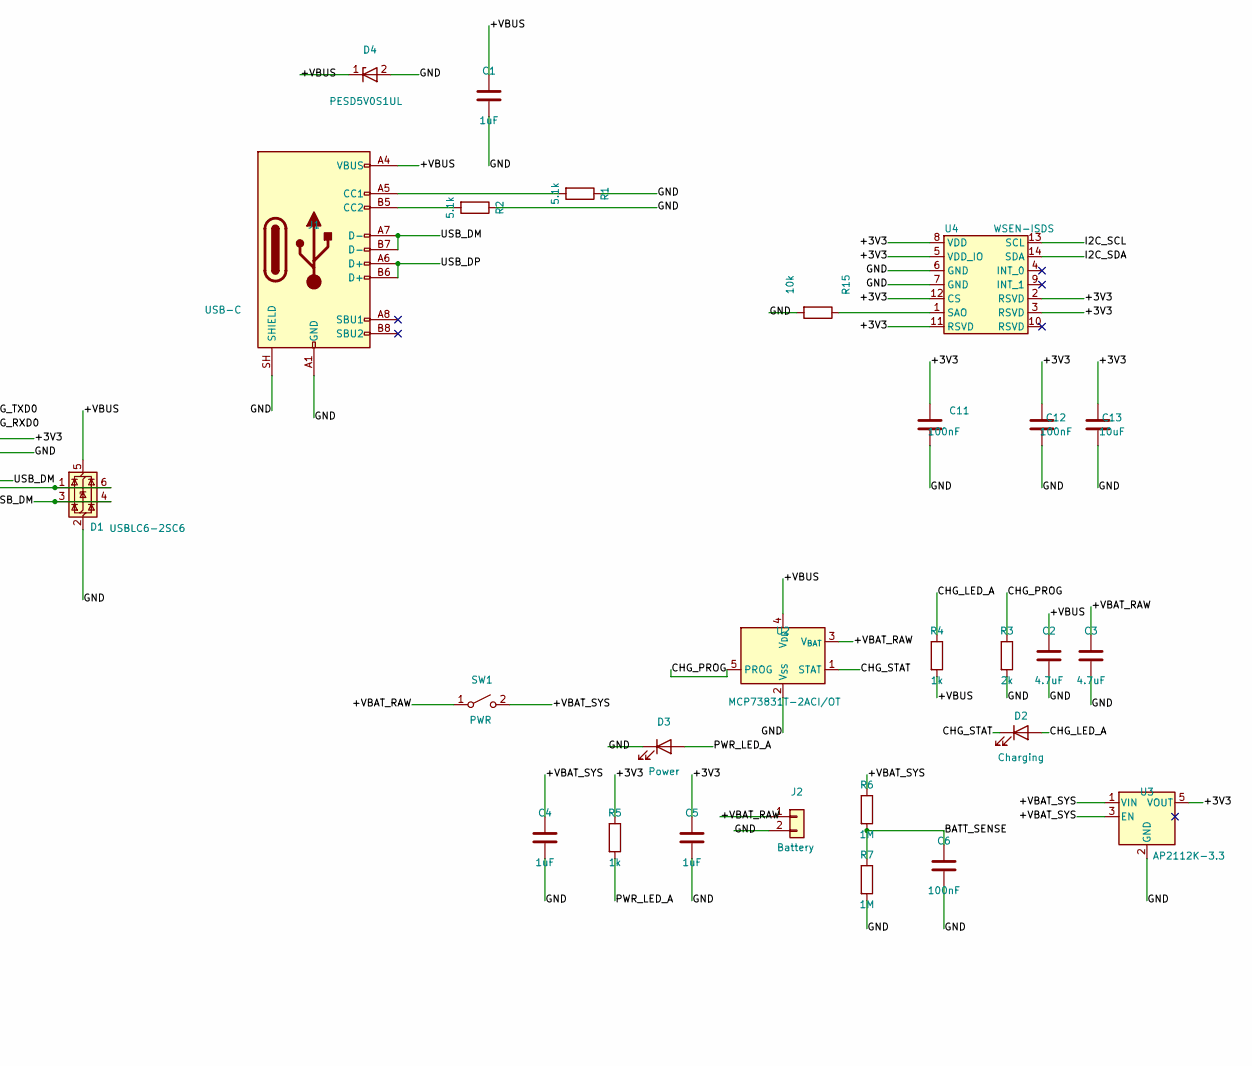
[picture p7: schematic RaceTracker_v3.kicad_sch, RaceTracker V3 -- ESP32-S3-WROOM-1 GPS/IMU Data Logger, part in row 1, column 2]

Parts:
C1, C4, C5, C9: 1uF; C_0603_1608Metric; MPN CL10A105KB8NNNC; LCSC C15849
C2, C3: 4.7uF; C_0603_1608Metric; MPN CL10A475KO8NNNC; LCSC C19666
C6, C8, C10, C11, C12: 100nF; C_0603_1608Metric; MPN CC0603KRX7R9BB104; LCSC C14663
C7: 22uF; C_0805_2012Metric; MPN CL21A226MAQNNNE; LCSC C45783
C13: 10uF; C_0805_2012Metric; MPN CL21A106KAYNNNE; LCSC C15850
D1: USBLC6-2SC6; SOT-23-6; MPN USBLC6-2SC6; LCSC C2687116
D2: Charging; LED_0603_1608Metric; MPN XL-1608SURC-06; LCSC C965799
D3: Power; LED_0603_1608Metric; MPN XL-1608UGC-04; LCSC C965804
D4: PESD5V0S1UL; D_SOD-882; MPN PESD5V0S1UL; LCSC C85402
J1: USB-C; USB_C_Receptacle_HRO_TYPE-C-31-M-12; MPN TYPE-C-31-M-12; LCSC C165948
J2: Battery; JST_PH_S2B-PH-SM4-TB_1x02-1MP_P2.00mm_Horizontal; MPN S2B-PH-SM4-TB(LF)(SN); LCSC C295747
J3: Qwiic GPS (I2C); PinHeader_1x04_P2.54mm_Vertical; MPN PZ254V-11-04P; LCSC C2691448
J4: microSD; microSD_HC_Molex_104031-0811; MPN 104031-0811; LCSC C585350
J5: UART Debug; PinHeader_1x04_P2.54mm_Vertical; MPN PZ254V-11-04P; LCSC C2691448
J6: e-Paper (steckbar) 8p; PinHeader_1x08_P2.54mm_Vertical; MPN PZ254V-11-08P; LCSC C492407
R1, R2: 5.1k; R_0603_1608Metric; MPN 0603WAF5101T5E; LCSC C23186
R3: 2k; R_0603_1608Metric; MPN 0603WAF2001T5E; LCSC C22975
R4, R5: 1k; R_0603_1608Metric; MPN 0603WAF1001T5E; LCSC C21190
R6, R7: 1M; R_0603_1608Metric; MPN 0603WAF1004T5E; LCSC C22935
R8, R9, R12, R13, R14, R15: 10k; R_0603_1608Metric; MPN 0603WAF1002T5E; LCSC C25804
R10, R11: 4.7k; R_0603_1608Metric; MPN 0603WAF4701T5E; LCSC C23162
SW1: PWR; SW_DIP_SPSTx01_Slide_6.7x4.1mm_W7.62mm_P2.54mm_LowProfile; MPN DSWB01LHGET; LCSC C126888
SW2: RESET; SW_SPST_B3U-1000P; MPN B3U-1000P; LCSC C231329
SW3: BOOT; SW_SPST_B3U-1000P; MPN B3U-1000P; LCSC C231329
U1: ESP32-S3-WROOM-1-N8; ESP32-S3-WROOM-1; MPN ESP32-S3-WROOM-1-N8; LCSC C2913198
U2: MCP73831T-2ACI/OT; SOT-23-5; MPN MCP73831T-2ACI/OT; LCSC C424093
U3: AP2112K-3.3; SOT-23-5; MPN AP2112K-3.3TRG1; LCSC C23380830
U4: WSEN-ISDS; LGA-14_3x2.5mm_P0.5mm_LayoutBorder3x4y; MPN 2536030320001

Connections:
/+3V3: C5.1, C7.1, C8.1, C11.1, C12.1, C13.1, J3.2, J4.4 (VDD), J5.2, J6.1, R5.1, R8.1, R9.1, R10.1, R11.1, R12.1, R13.1, R14.1, U1.2 (3V3), U3.5 (VOUT), U4.2 (RSVD), U4.3 (RSVD), U4.5 (VDD_IO), U4.8 (VDD), U4.11 (RSVD), U4.12 (CS)
/+VBAT_RAW: C3.1, J2.1, SW1.1 (A), U2.3 (V_{BAT})
/+VBAT_SYS: C4.1, R6.1, SW1.2 (B), U3.1 (VIN), U3.3 (EN)
/+VBUS: C1.1, C2.1, D1.5 (VBUS), D4.1 (K), J1.A4 (VBUS), J1.A9 (VBUS), J1.B4 (VBUS), J1.B9 (VBUS), R4.2, U2.4 (V_{DD})
/BATT_SENSE: C6.1, R6.2, R7.1, U1.28 (IO35)
/CHG_LED_A: D2.2 (A), R4.1
/CHG_PROG: R3.1, U2.5 (PROG)
/CHG_STAT: D2.1 (K), U2.1 (STAT)
/DBG_RXD0: J5.3, U1.36 (RXD0)
/DBG_TXD0: J5.4, U1.37 (TXD0)
/EPD_BUSY: J6.7, U1.7 (IO7)
/EPD_CS: J6.4, U1.4 (IO4)
/EPD_DC: J6.5, U1.5 (IO5)
/EPD_RST: J6.6, U1.6 (IO6)
/GND: C1.2, C2.2, C3.2, C4.2, C5.2, C6.2, C7.2, C8.2, C9.1, C10.1, C11.2, C12.2, C13.2, D1.2 (GND), D3.1 (K), D4.2 (A), J1.A1 (GND), J1.A12 (GND), J1.B1 (GND), J1.B12 (GND), J1.SH (SHIELD), J2.2, J3.1, J4.6 (VSS), J4.9 (DET_B), J4.SH (SHIELD), J5.1, J6.8, R1.1, R2.1, R3.2, R7.2, R15.2, SW2.1, SW3.1, U1.1 (GND), U1.40 (GND), U1.41 (GND), U2.2 (V_{SS}), U3.2 (GND), U4.6 (GND), U4.7 (GND)
/I2C_SCL: J3.4, R11.2, U1.17 (IO9), U4.13 (SCL)
/I2C_SDA: J3.3, R10.2, U1.12 (IO8), U4.14 (SDA)
/PWR_LED_A: D3.2 (A), R5.2
/SD_CD: J4.10 (DET_A), R14.2, U1.22 (IO14)
/SD_CS: J4.2 (DAT3/CD), R12.2, U1.18 (IO10)
/SD_MISO: J4.7 (DAT0), R13.2, U1.21 (IO13)
/SD_MOSI: J4.3 (CMD), J6.2, U1.19 (IO11)
/SD_SCK: J4.5 (CLK), J6.3, U1.20 (IO12)
/USB_DM: D1.3 (I/O2), D1.4 (I/O2), J1.A7 (D-), J1.B7 (D-), U1.13 (USB_D-)
/USB_DP: D1.1 (I/O1), D1.6 (I/O1), J1.A6 (D+), J1.B6 (D+), U1.14 (USB_D+)
unnamed: J1.A5 (CC1), R1.2
unnamed: J1.B5 (CC2), R2.2
unnamed: C9.2, C10.2, R8.2, SW2.2, U1.3 (EN)
unnamed: R9.2, SW3.2, U1.27 (IO0)
unnamed: R15.1, U4.1 (SAO)

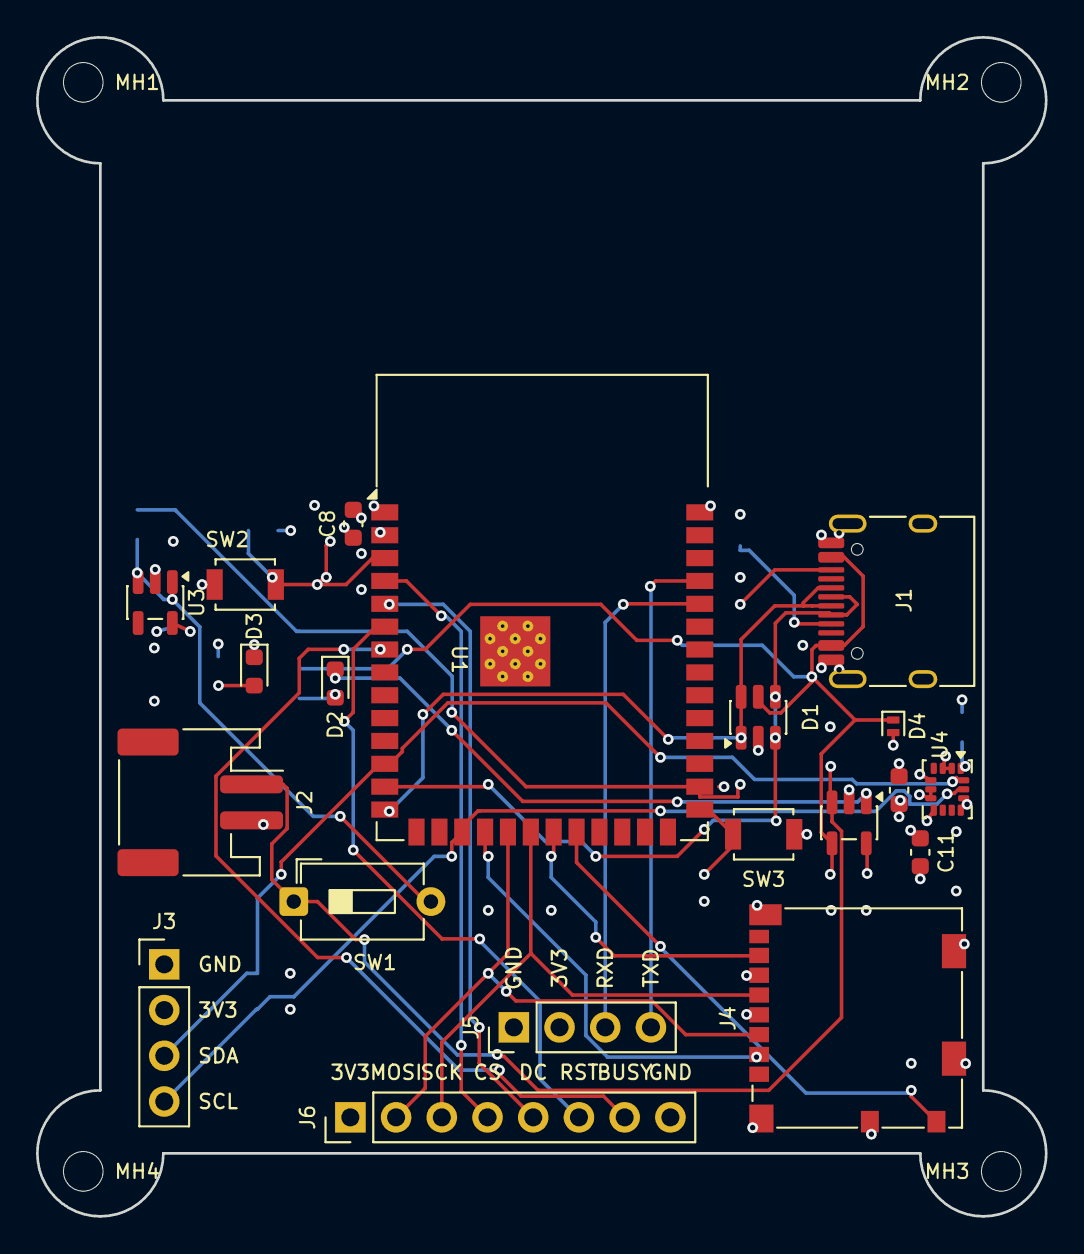
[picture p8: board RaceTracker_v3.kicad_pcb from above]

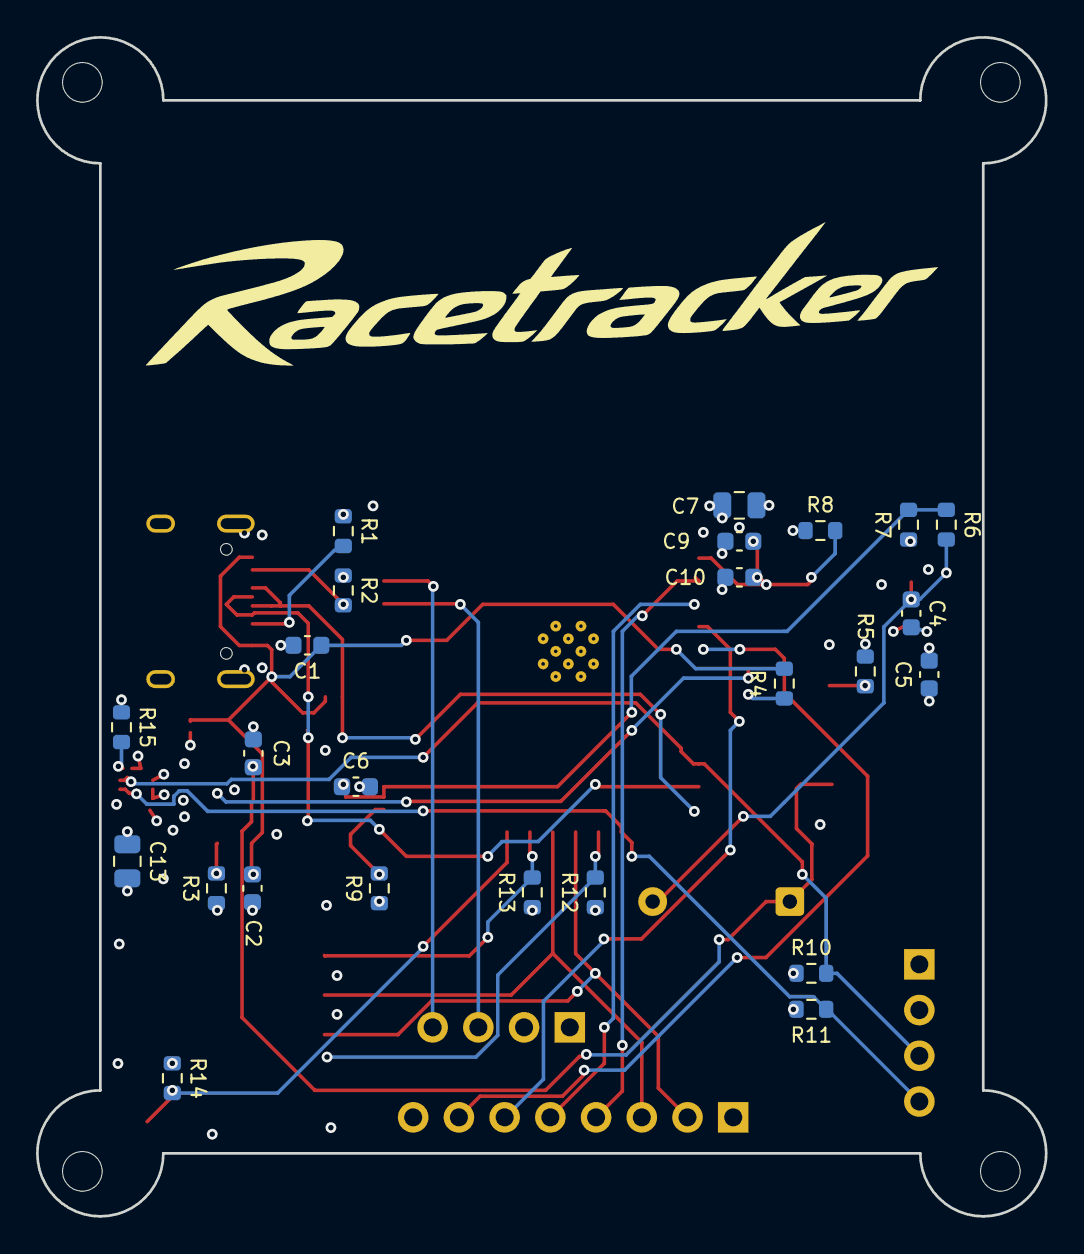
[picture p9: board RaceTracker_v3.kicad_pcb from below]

Board: 4 copper layers, 56.0 x 65.5 mm, 49 parts (25 on the bottom side), 30 nets.

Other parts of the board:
MH1, MH2, MH3, MH4: MountingHole_2.2mm_M2

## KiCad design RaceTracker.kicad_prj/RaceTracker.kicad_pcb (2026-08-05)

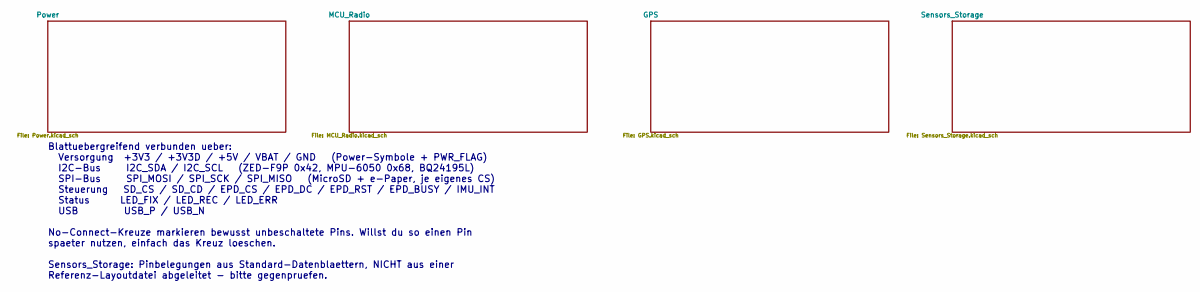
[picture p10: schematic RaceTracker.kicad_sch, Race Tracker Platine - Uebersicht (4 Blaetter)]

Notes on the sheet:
Blattuebergreifend verbunden ueber: Versorgung +3V3 / +3V3D / +5V / VBAT / GND (Power-Symbole + PWR_FLAG) I2C-Bus I2C_SDA / I2C_SCL (ZED-F9P 0x42, MPU-6050 0x68, BQ24195L) SPI-Bus SPI_MOSI / SPI_SCK / SPI_MISO (MicroSD + e-Paper, je eigenes CS) Steuerung SD_CS / SD_CD / EPD_CS / EPD_DC / EPD_RST / 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

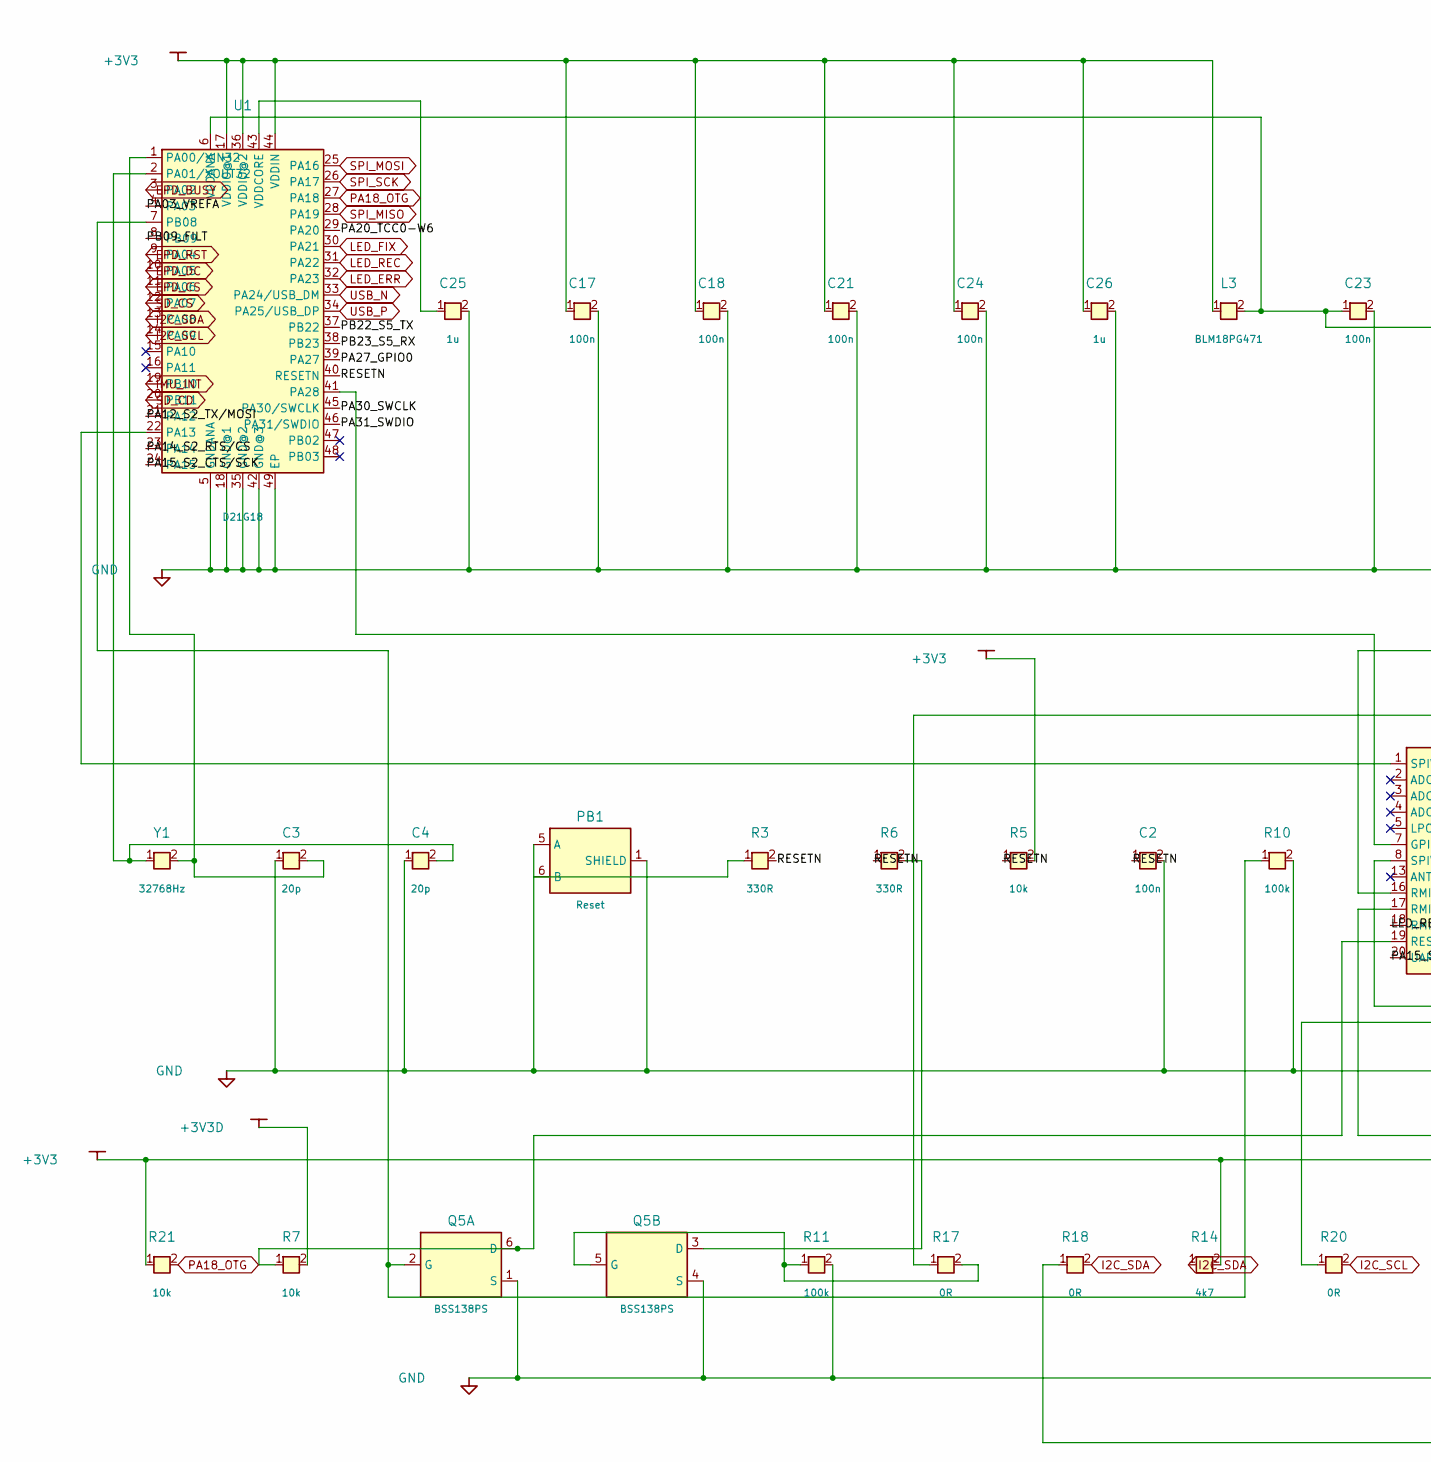
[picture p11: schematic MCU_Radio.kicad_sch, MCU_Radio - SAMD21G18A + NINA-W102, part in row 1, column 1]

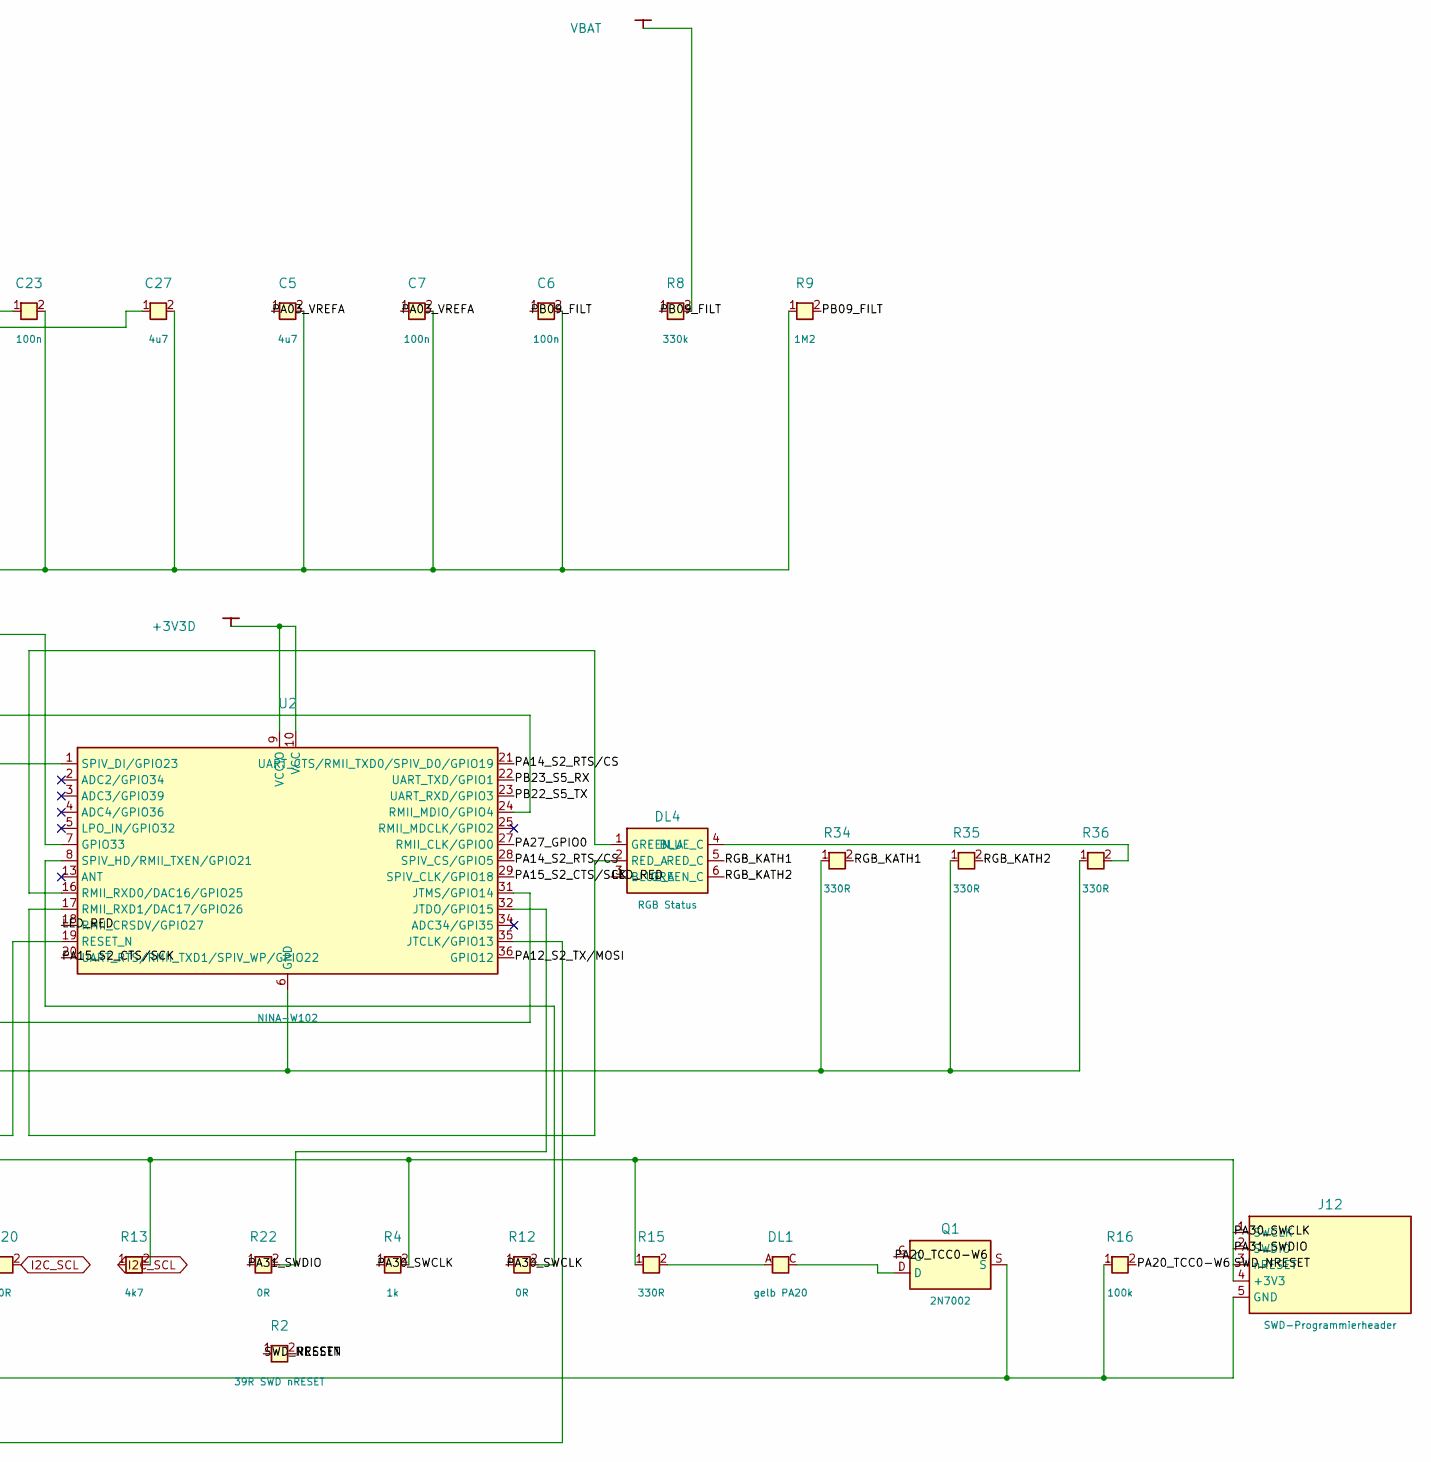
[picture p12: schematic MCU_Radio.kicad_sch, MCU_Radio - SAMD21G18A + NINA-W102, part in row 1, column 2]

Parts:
C2, C6, C7, C17, C18, C21, C23, C24: 100n; C_0402_1005Metric
C3, C4: 20p; C_0402_1005Metric
C5: 4u7; C_0402_1005Metric
C25, C26: 1u; C_0402_1005Metric
C27: 4u7; C_0603_1608Metric
DL1: gelb PA20; LED_0603_AK
DL4: RGB Status; RGBLED_5050
J12: SWD-Programmierheader; PinHeader_1x05_P2.54mm_Vertical
L3: BLM18PG471; L_0603_1608Metric
PB1: Reset; PTS820_NO_HOLES
Q1: 2N7002; SOTFL50P160X78-3
Q5: BSS138PS; SOT363
R2: 39R SWD nRESET; R_0402_1005Metric
R3, R6, R15, R34, R35, R36: 330R; R_0402_1005Metric
R4: 1k; R_0402_1005Metric
R5, R7, R21: 10k; R_0402_1005Metric
R8: 330k; R_0402_1005Metric
R9: 1M2; R_0402_1005Metric
R10, R11, R16: 100k; R_0402_1005Metric
R12, R17, R18, R20, R22: 0R; R_0402_1005Metric
R13, R14: 4k7; R_0402_1005Metric
U1: D21G18; QFN48_SAMD21G18A
U2: NINA-W102; NINA_W1X_MODULE
Y1: 32768Hz; ABS07_CRYSTAL

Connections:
+3V3D: R7.2, U2.9 (VCCIO), U2.10 (VCC); also elsewhere on the board
/MCU_Radio/LED_RED: DL4.3 (BLUE_A), U2.18 (RMII_CRSDV/GPIO27)
/MCU_Radio/PA03_VREFA: C5.1, C7.1, U1.4 (PA03)
/MCU_Radio/PA12_S2_TX/MOSI: U1.21 (PA12), U2.36 (GPIO12)
/MCU_Radio/PA14_S2_RTS/CS: U1.23 (PA14), U2.21 (UART_CTS/RMII_TXD0/SPIV_D0/GPIO19), U2.28 (SPIV_CS/GPIO5)
/MCU_Radio/PA15_S2_CTS/SCK: U1.24 (PA15), U2.20 (UART_RTS/RMII_TXD1/SPIV_WP/GPIO22), U2.29 (SPIV_CLK/GPIO18)
/MCU_Radio/PA20_TCC0-W6: Q1.G, R16.2, U1.29 (PA20)
/MCU_Radio/PA27_GPIO0: U1.39 (PA27), U2.27 (RMII_CLK/GPIO0)
/MCU_Radio/PB09_FILT: C6.1, R8.1, R9.2, U1.8 (PB09)
/MCU_Radio/PB22_S5_TX: U1.37 (PB22), U2.23 (UART_RXD/GPIO3)
/MCU_Radio/PB23_S5_RX: U1.38 (PB23), U2.22 (UART_TXD/GPIO1)
/MCU_Radio/RESETN: C2.1, R2.2, R3.2, R5.1, R6.1, U1.40 (RESETN)
/MCU_Radio/RGB_KATH1: DL4.5 (RED_C), R34.2
/MCU_Radio/RGB_KATH2: DL4.6 (GREEN_C), R35.2
EPD_BUSY: U1.3 (PA02); also elsewhere on the board
EPD_CS: U1.11 (PA06); also elsewhere on the board
EPD_DC: U1.10 (PA05); also elsewhere on the board
EPD_RST: U1.9 (PA04); also elsewhere on the board
GND: C2.2, C3.1, C4.1, C5.2, C6.2, C7.2, C17.2, C18.2, C21.2, C23.2, C24.2, C25.2, C26.2, C27.2, J12.5 (GND), PB1.1 (SHIELD), PB1.2 (SHIELD), PB1.3 (SHIELD), PB1.4 (SHIELD), PB1.5 (A), Q1.S, Q5.1 (S), Q5.4 (S), R9.1, R10.2, R11.2, R16.1, R34.1, R35.1, R36.1, U1.5 (GNDANA), U1.18 (GND@1), U1.35 (GND@2), U1.42 (GND@3), U1.49 (EP), U2.6 (GND), U2.12, U2.14, U2.26, U2.30, U2.GND@1, U2.GND@2, U2.GND@3, U2.GND@4, U2.GND@5, U2.GND@6, U2.GND@7, U2.GND@8, U2.GND@9, U2.GND@10, U2.GND@11, U2.GND@12; also elsewhere on the board
I2C_SCL: R13.1, R20.2, U1.14 (PA09); also elsewhere on the board
I2C_SDA: R14.1, R18.2, U1.13 (PA08); also elsewhere on the board
IMU_INT: U1.19 (PB10); also elsewhere on the board
LED_ERR: U1.32 (PA23); also elsewhere on the board
LED_FIX: U1.30 (PA21); also elsewhere on the board
LED_REC: U1.31 (PA22); also elsewhere on the board
unnamed: DL1.A, R15.2
unnamed: DL1.C, Q1.D
unnamed: DL4.4 (BLUE_C), R36.2
unnamed: DL4.1 (GREEN_A), U2.16 (RMII_RXD0/DAC16/GPIO25)
unnamed: DL4.2 (RED_A), U2.17 (RMII_RXD1/DAC17/GPIO26)
unnamed: PB1.6 (B), R3.1
unnamed: Q5.6 (D), R7.1, U2.19 (RESET_N)
unnamed: Q5.2 (G), R10.1, U1.7 (PB08)
unnamed: Q5.3 (D), R6.2
unnamed: Q5.5 (G), R11.1, R17.2
unnamed: C3.2, U1.1 (PA00/XIN32), Y1.2
unnamed: C4.2, U1.2 (PA01/XOUT32), Y1.1
unnamed: U1.22 (PA13), U2.1 (SPIV_DI/GPIO23)
unnamed: U1.41 (PA28), U2.7 (GPIO33)
unnamed: C23.1, C27.1, L3.2, U1.6 (VDDANA)
unnamed: C25.1, U1.43 (VDDCORE)
unnamed: R18.1, U2.35 (JTCLK/GPIO13)
unnamed: R22.2, U2.32 (JTDO/GPIO15)
unnamed: R20.1, U2.31 (JTMS/GPIO14)
unnamed: R17.1, U2.24 (RMII_MDIO/GPIO4)
unnamed: R12.2, U2.8 (SPIV_HD/RMII_TXEN/GPIO21)
PA18_OTG: R21.2, U1.27 (PA18); also elsewhere on the board
SD_CD: U1.20 (PB11); also elsewhere on the board
SD_CS: U1.12 (PA07); also elsewhere on the board
SPI_MISO: U1.28 (PA19); also elsewhere on the board
SPI_MOSI: U1.25 (PA16); also elsewhere on the board
SPI_SCK: U1.26 (PA17); also elsewhere on the board
USB_P: U1.34 (PA25/USB_DP); also elsewhere on the board
VBAT: R8.2; also elsewhere on the board

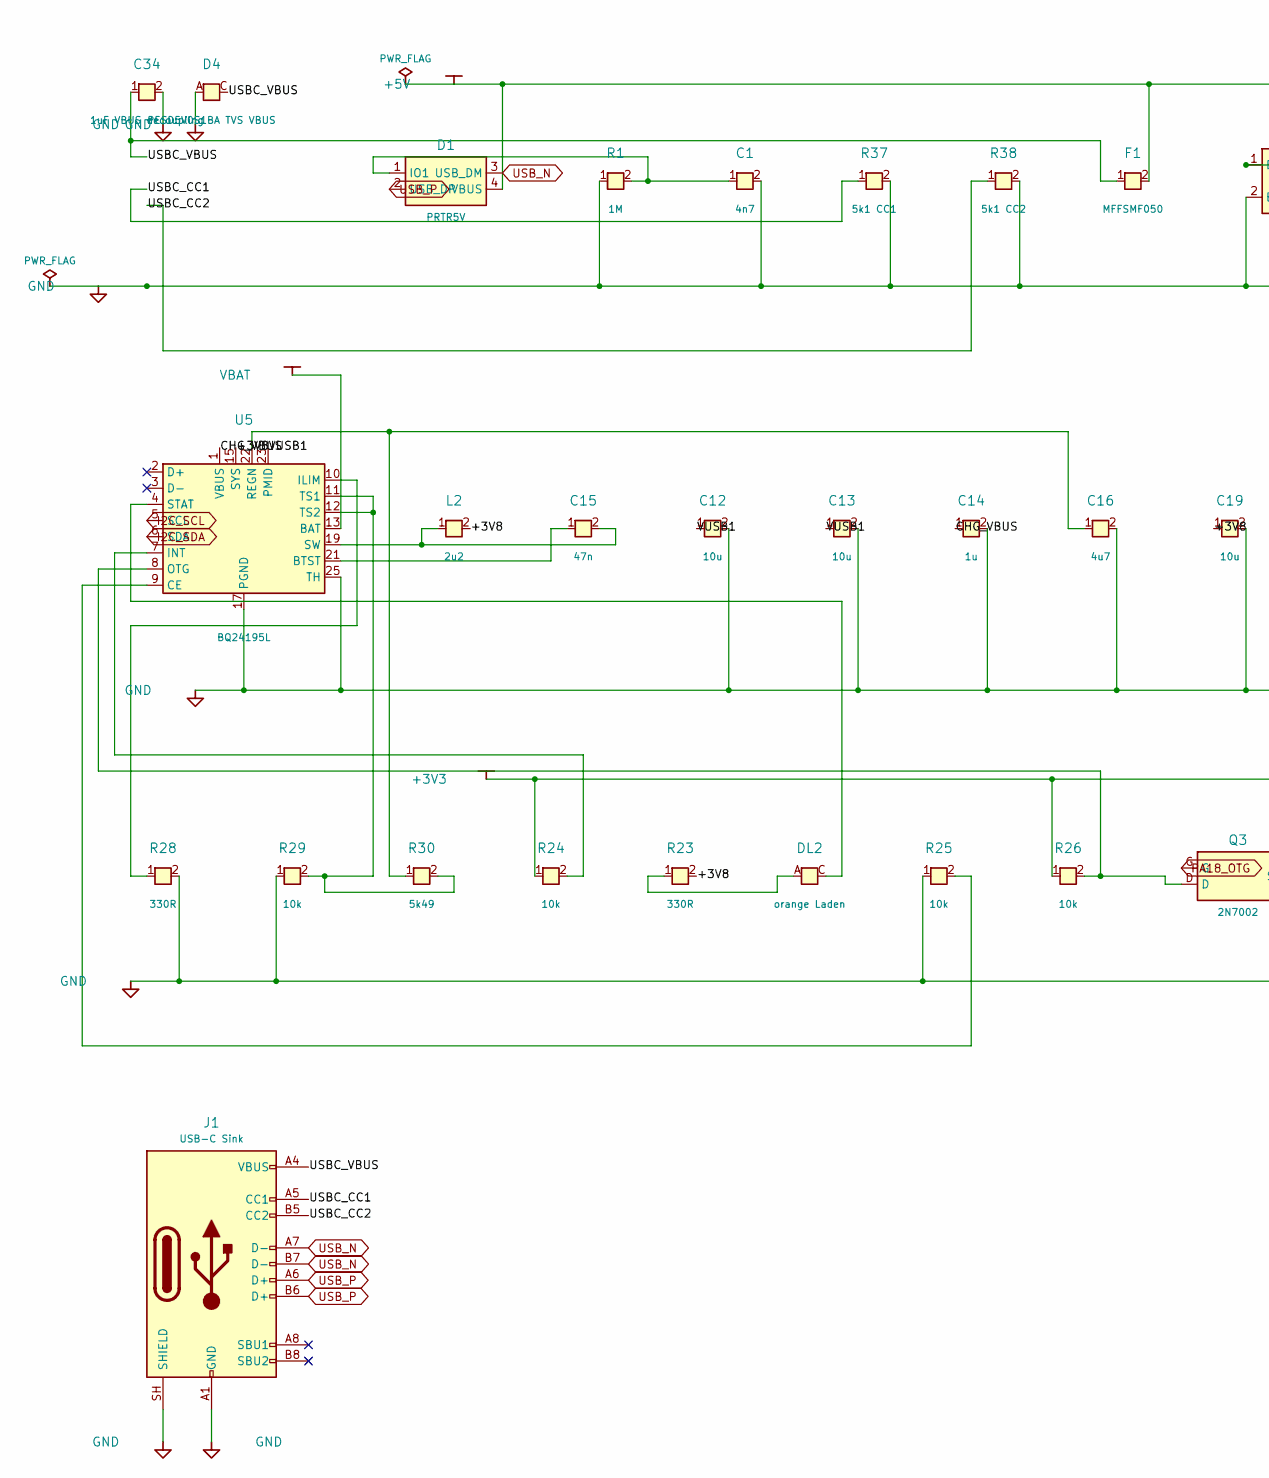
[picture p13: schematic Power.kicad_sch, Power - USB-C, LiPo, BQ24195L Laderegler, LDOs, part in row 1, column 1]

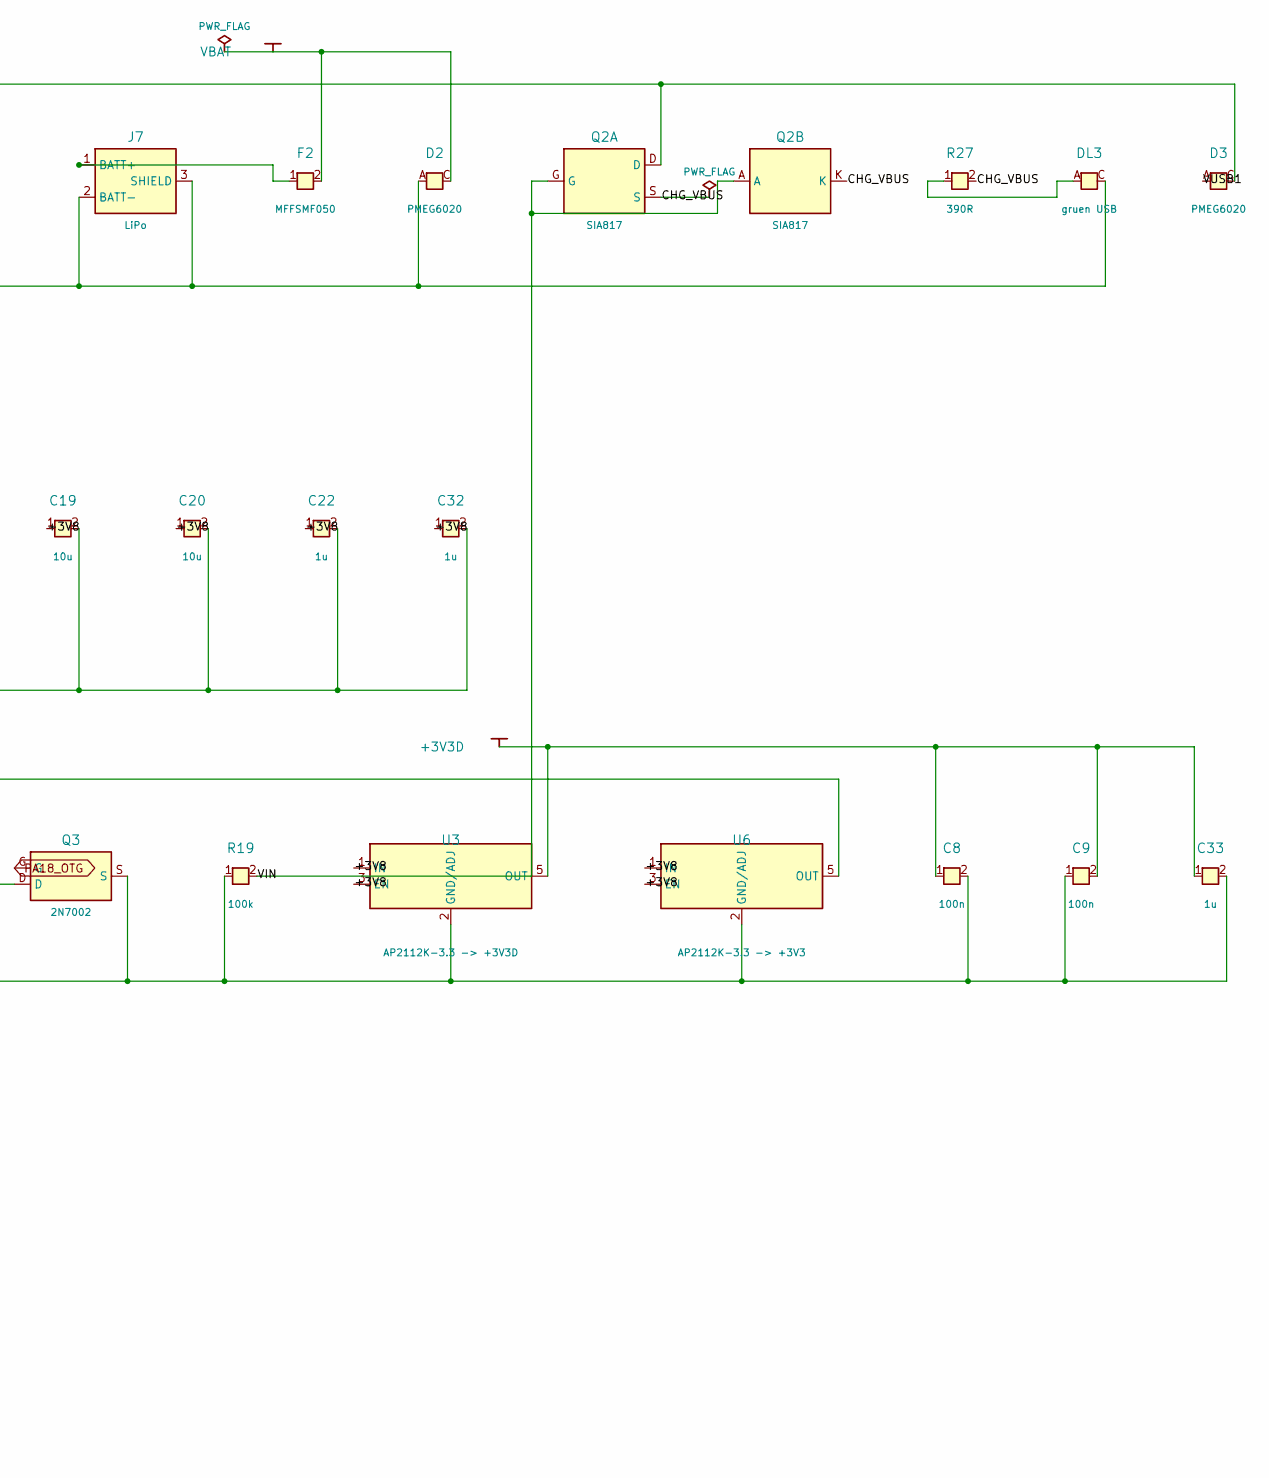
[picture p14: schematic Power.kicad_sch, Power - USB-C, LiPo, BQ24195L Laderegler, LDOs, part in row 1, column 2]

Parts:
C1: 4n7; C_0805_2012Metric
C8, C9: 100n; C_0402_1005Metric
C12, C13, C19, C20: 10u; C_0603_1608Metric
C14, C22, C32, C33: 1u; C_0402_1005Metric
C15: 47n; C_0402_1005Metric
C16: 4u7; C_0402_1005Metric
C34: 1uF VBUS decoupling; C_0402_1005Metric
D1: PRTR5V; SOT143B_4N; MPN PRTR5V0U2X,215
D2, D3: PMEG6020; SODFL3517X110N
D4: PESD5V0S1BA TVS VBUS; D_SOD-323; MPN PESD5V0S1BA
DL2: orange Laden; LED_0603_AK
DL3: gruen USB; LED_0603_AK
F1, F2: MFFSMF050; Fuse_0603_1608Metric
J1: USB-C Sink; USB_C_Receptacle_HRO_TYPE-C-31-M-12; MPN TYPE-C-31-M-12
J7: LiPo; JST_S2B_PH_SM4_TB
L2: 2u2; SRP4020
Q2: SIA817; SON65P205X205X75-8N-MWSD
Q3: 2N7002; SOTFL50P160X78-3
R1: 1M; R_0402_1005Metric
R19: 100k; R_0402_1005Metric
R23, R28: 330R; R_0402_1005Metric
R24, R25, R26, R29: 10k; R_0402_1005Metric
R27: 390R; R_0402_1005Metric
R30: 5k49; R_0402_1005Metric
R37: 5k1 CC1; R_0402_1005Metric
R38: 5k1 CC2; R_0402_1005Metric
U3: AP2112K-3.3 -> +3V3D; SOT25
U5: BQ24195L; QFN24_BQ24195L
U6: AP2112K-3.3 -> +3V3; SOT25

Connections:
+3V3D: C8.1, C9.2, C33.1, U3.5 (OUT); also elsewhere on the board
/Power/+3V8: C19.1, C20.1, C22.1, C32.1, L2.2, R23.2, U3.1 (IN), U3.3 (EN), U5.15 (SYS), U5.16, U6.1 (IN), U6.3 (EN)
/Power/CHG_VBUS: C14.1, Q2.K, Q2.K2, Q2.S, R27.2, U5.1 (VBUS), U5.24
/Power/USBC_CC1: J1.A5 (CC1), R37.1
/Power/USBC_CC2: J1.B5 (CC2), R38.1
/Power/USBC_VBUS: C34.1, D4.C, F1.1, J1.A4 (VBUS), J1.A9 (VBUS), J1.B4 (VBUS), J1.B9 (VBUS)
/Power/VIN: Q2.A, Q2.G, R19.2
/Power/VUSB1: C12.1, C13.1, D3.A, U5.23 (PMID)
GND: C1.2, C8.2, C9.1, C12.2, C13.2, C14.2, C16.2, C19.2, C20.2, C22.2, C32.2, C33.2, C34.2, D2.A, D4.A, DL3.C, J1.A1 (GND), J1.A12 (GND), J1.B1 (GND), J1.B12 (GND), J1.SH (SHIELD), J7.2 (BATT-), J7.3 (SHIELD), J7.4 (SHIELD), Q3.S, R1.1, R19.1, R25.1, R28.2, R29.1, R37.2, R38.2, U3.2 (GND/ADJ), U5.17 (PGND), U5.18, U5.25 (TH), U6.2 (GND/ADJ); also elsewhere on the board
I2C_SCL: U5.5 (SCL); also elsewhere on the board
I2C_SDA: U5.6 (SDA); also elsewhere on the board
unnamed: C1.1, D1.1 (IO1), R1.2
unnamed: DL2.A, R23.1
unnamed: DL3.A, R27.1
unnamed: F2.1, J7.1 (BATT+)
unnamed: C15.1, U5.21 (BTST)
unnamed: R25.2, U5.9 (CE)
unnamed: R28.1, U5.10 (ILIM)
unnamed: R24.2, U5.7 (INT)
unnamed: Q3.D, R26.2, U5.8 (OTG)
unnamed: C16.1, R30.1, U5.22 (REGN)
unnamed: DL2.C, U5.4 (STAT)
unnamed: C15.2, L2.1, U5.19 (SW), U5.20
unnamed: R29.2, R30.2, U5.11 (TS1), U5.12 (TS2)
PA18_OTG: Q3.G; also elsewhere on the board
USB_P: D1.2 (USB_DP), J1.A6 (D+), J1.B6 (D+); also elsewhere on the board
VBAT: D2.C, F2.2, U5.13 (BAT), U5.14; also elsewhere on the board

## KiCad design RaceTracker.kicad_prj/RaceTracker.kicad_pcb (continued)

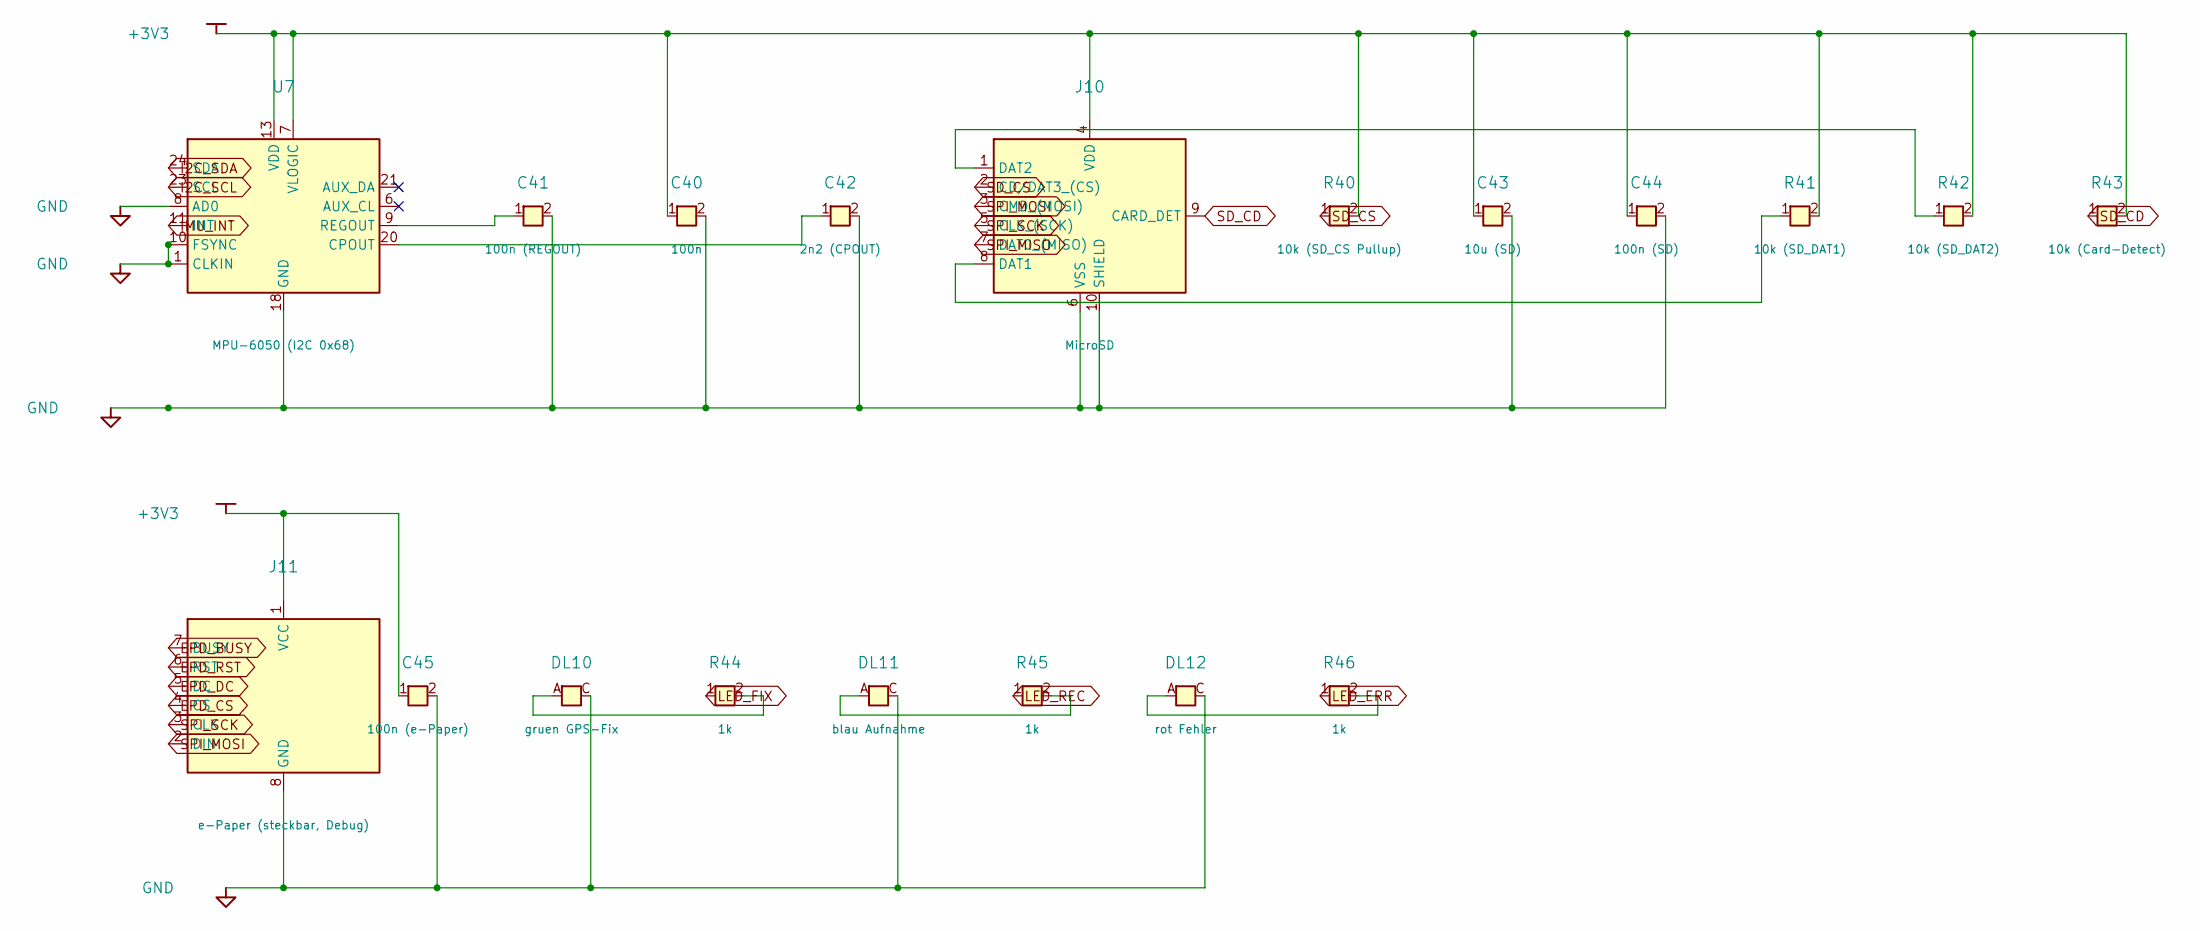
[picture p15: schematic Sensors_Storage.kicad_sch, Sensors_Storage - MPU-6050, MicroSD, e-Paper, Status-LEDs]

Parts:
C40: 100n; C_0402_1005Metric
C41: 100n (REGOUT); C_0402_1005Metric
C42: 2n2 (CPOUT); C_0402_1005Metric
C43: 10u (SD); C_0603_1608Metric
C44: 100n (SD); C_0402_1005Metric
C45: 100n (e-Paper); C_0402_1005Metric
DL10: gruen GPS-Fix; LED_0603_AK
DL11: blau Aufnahme; LED_0603_AK
DL12: rot Fehler; LED_0603_AK
J10: MicroSD; microSD_HC_Molex_104031-0811
J11: e-Paper (steckbar, Debug); PinHeader_1x08_P2.54mm_Vertical
R40: 10k (SD_CS Pullup); R_0402_1005Metric
R41: 10k (SD_DAT1); R_0402_1005Metric
R42: 10k (SD_DAT2); R_0402_1005Metric
R43: 10k (Card-Detect); R_0402_1005Metric
R44, R45, R46: 1k; R_0402_1005Metric
U7: MPU-6050 (I2C 0x68); InvenSense_QFN-24_4x4mm_P0.5mm

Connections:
EPD_BUSY: J11.7 (BUSY); also elsewhere on the board
EPD_CS: J11.4 (CS); also elsewhere on the board
EPD_DC: J11.5 (DC); also elsewhere on the board
EPD_RST: J11.6 (RST); also elsewhere on the board
GND: C40.2, C41.2, C42.2, C43.2, C44.2, C45.2, DL10.C, DL11.C, DL12.C, J10.6 (VSS), J10.10 (SHIELD), J11.8 (GND), U7.1 (CLKIN), U7.8 (AD0), U7.10 (FSYNC), U7.18 (GND); also elsewhere on the board
I2C_SCL: U7.23 (SCL); also elsewhere on the board
I2C_SDA: U7.24 (SDA); also elsewhere on the board
IMU_INT: U7.11 (INT); also elsewhere on the board
LED_ERR: R46.1; also elsewhere on the board
LED_FIX: R44.1; also elsewhere on the board
LED_REC: R45.1; also elsewhere on the board
unnamed: DL10.A, R44.2
unnamed: DL11.A, R45.2
unnamed: DL12.A, R46.2
unnamed: J10.8 (DAT1), R41.1
unnamed: J10.1 (DAT2), R42.1
unnamed: C42.1, U7.20 (CPOUT)
unnamed: C41.1, U7.9 (REGOUT)
SD_CD: J10.9 (CARD_DET), R43.1; also elsewhere on the board
SD_CS: J10.2 (CD/DAT3_(CS)), R40.1; also elsewhere on the board
SPI_MISO: J10.7 (DAT0_(MISO)); also elsewhere on the board
SPI_MOSI: J10.3 (CMD_(MOSI)), J11.2 (DIN); also elsewhere on the board
SPI_SCK: J10.5 (CLK_(SCK)), J11.3 (CLK); also elsewhere on the board

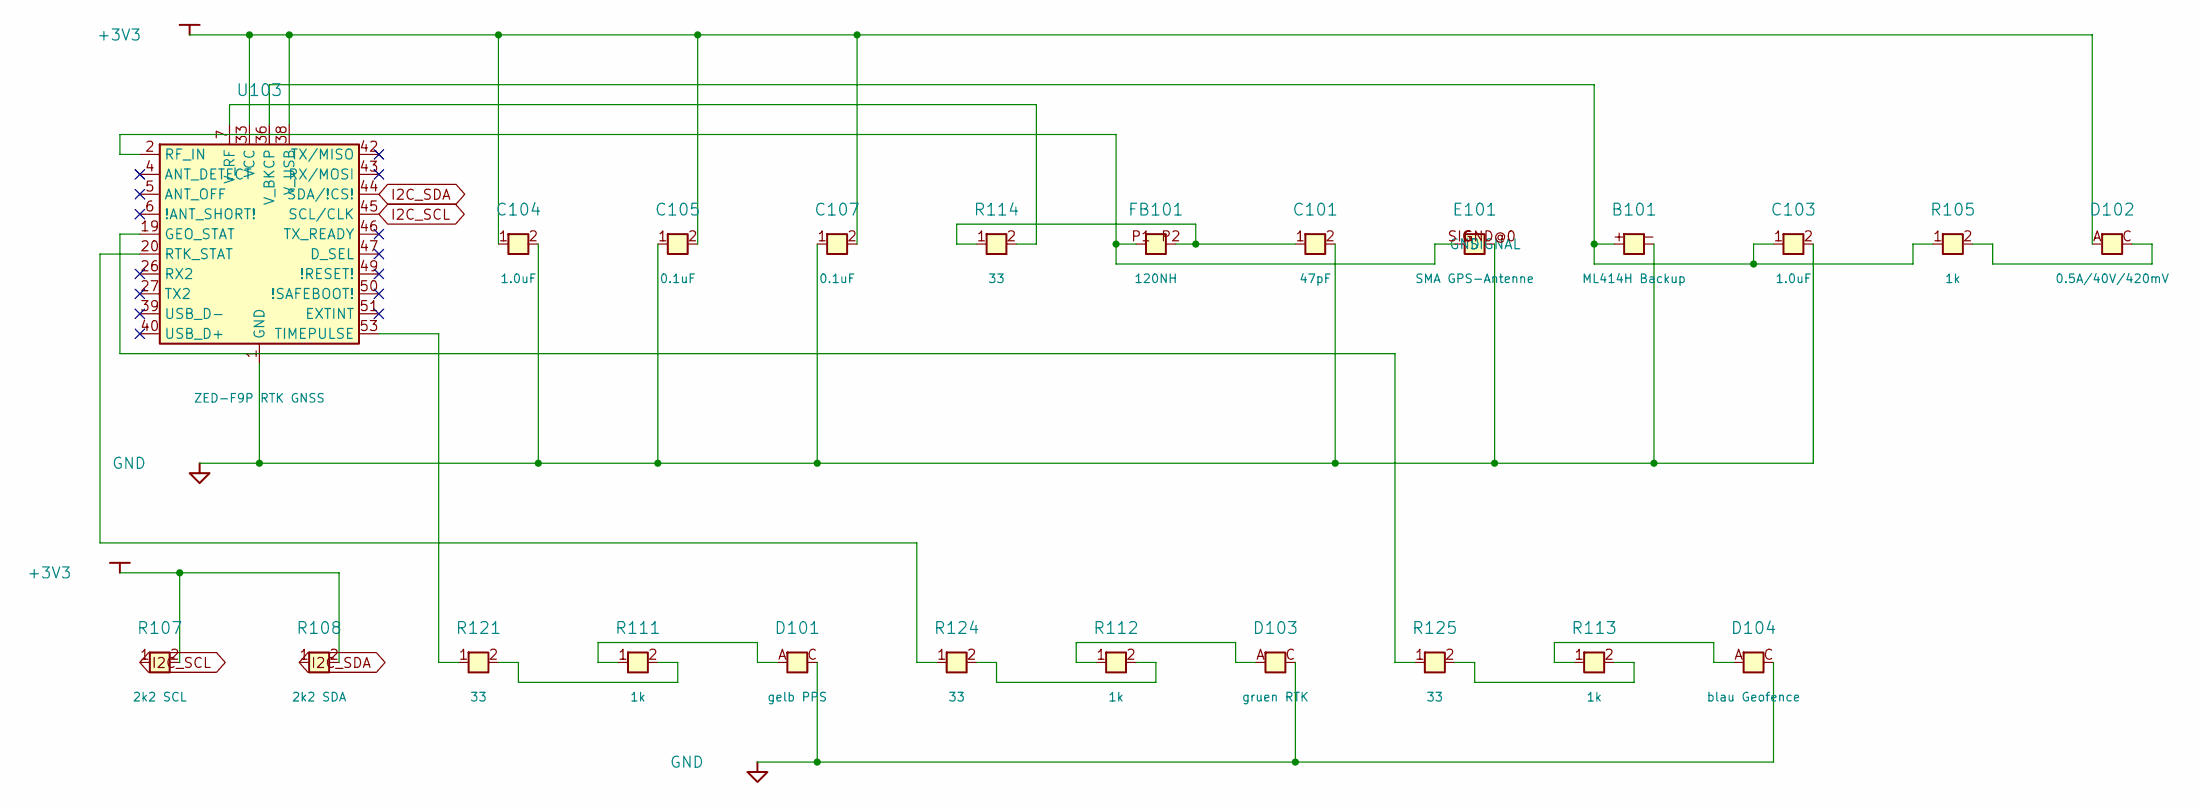
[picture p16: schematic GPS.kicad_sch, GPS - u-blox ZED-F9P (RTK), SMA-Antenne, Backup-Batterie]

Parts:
B101: ML414H Backup; ML414H_COIN_CELL
C101: 47pF; C_0402_1005Metric
C103, C104: 1.0uF; C_0402_1005Metric
C105, C107: 0.1uF; C_0402_1005Metric
D101: gelb PPS; LED_0603_AK
D102: 0.5A/40V/420mV; SODFL3517X110N
D103: gruen RTK; LED_0603_AK
D104: blau Geofence; LED_0603_AK
E101: SMA GPS-Antenne; SMA_EDGE
FB101: 120NH; L_0402_1005Metric
R105, R111, R112, R113: 1k; R_0402_1005Metric
R107: 2k2 SCL; R_0402_1005Metric
R108: 2k2 SDA; R_0402_1005Metric
R114, R121, R124, R125: 33; R_0402_1005Metric
U103: ZED-F9P RTK GNSS; ZED_F9P_LGA102

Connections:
GND: B101.-, C101.2, C103.2, C104.2, C105.1, C107.1, D101.C, D103.C, D104.C, E101.GND@0 (GND), E101.GND@1 (GND), E101.GND@2 (GND), E101.GND@3 (GND), U103.1 (GND), U103.3, U103.12, U103.14, U103.32, U103.37, U103.41, U103.48, U103.55, U103.56, U103.57, U103.58, U103.59, U103.60, U103.61, U103.62, U103.63, U103.64, U103.65, U103.66, U103.67, U103.68, U103.69, U103.70, U103.71, U103.72, U103.73, U103.74, U103.75, U103.76, U103.77, U103.78, U103.79, U103.80, U103.81, U103.82, U103.83, U103.84, U103.85, U103.86, U103.87, U103.88, U103.89, U103.90, U103.91, U103.92, U103.93, U103.94, U103.95, U103.96, U103.97, U103.98, U103.99, U103.100, U103.101, U103.102; also elsewhere on the board
I2C_SCL: R107.1, U103.45 (SCL/CLK); also elsewhere on the board
I2C_SDA: R108.1, U103.44 (SDA/!CS!); also elsewhere on the board
unnamed: C101.1, FB101.P2, R114.1
unnamed: D101.A, R111.1
unnamed: D102.C, R105.2
unnamed: D103.A, R112.1
unnamed: D104.A, R113.1
unnamed: E101.SIG (SIGNAL), FB101.P1, U103.2 (RF_IN)
unnamed: R111.2, R121.2
unnamed: R112.2, R124.2
unnamed: R113.2, R125.2
unnamed: R125.1, U103.19 (GEO_STAT)
unnamed: R124.1, U103.20 (RTK_STAT)
unnamed: R121.1, U103.53 (TIMEPULSE)
unnamed: B101.+, C103.1, R105.1, U103.36 (V_BKCP)
unnamed: R114.2, U103.7 (V_RF)

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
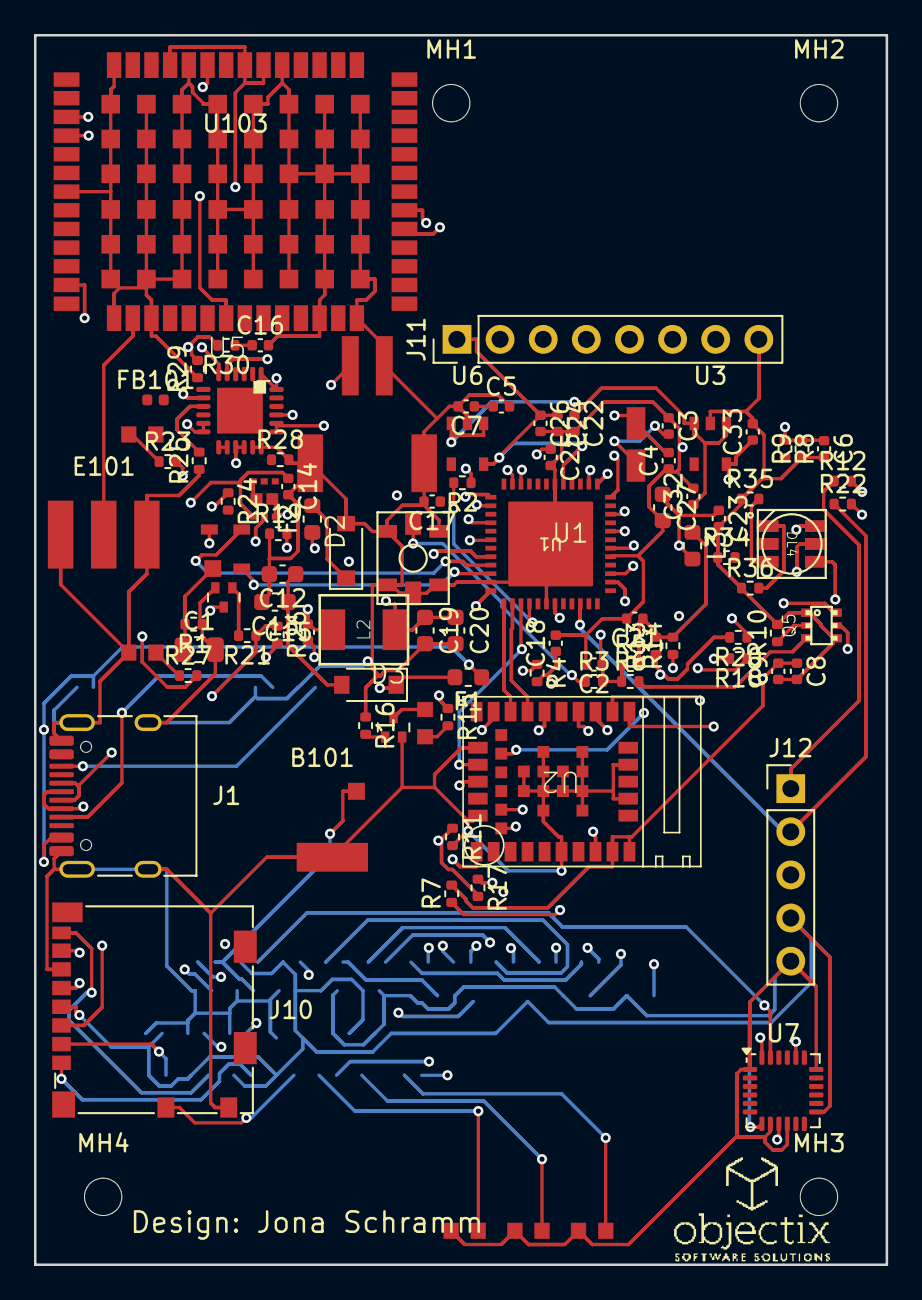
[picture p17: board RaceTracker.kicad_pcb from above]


Board: 4 copper layers, 50.2 x 72.4 mm, 135 parts (36 on the bottom side), 101 nets.

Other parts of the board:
MH1, MH2, MH3, MH4: MountingHole_2.2mm_M2

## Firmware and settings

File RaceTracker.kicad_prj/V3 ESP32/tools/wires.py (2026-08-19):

"""Net list.

Routing policy (matches the user's brief: direct wires dominate, labels
for long distances/readability):
  - A pin-to-pin hop is drawn as a real wire ONLY when the two components
    are immediately adjacent with nothing else in between (verified with
    check_crossings.py after every change -- KiCad connects wires wherever
    they touch or cross, even without a shared endpoint, so an unplanned
    crossing between two unrelated nets is a real short, not cosmetic).
  - Any run that would have to travel across the sheet through other
    components' territory (module <-> GPS/SD/UART connectors, and every
    shared power rail) uses a local label instead. Same-text local labels
    merge into one net anywhere on the sheet without a wire between them.
"""
from build_sch import COMPONENTS, snap

WIRES = []
LABELS = []
NO_CONNECTS = []
JUNCTIONS = []
PWR_FLAGS = []


def P(ref, pin):
    return COMPONENTS[ref].pin_pos(pin)


def wire(*pts):
    """One or more connected 2-point wire segments through the given
    (x,y) points (KiCad's `wire` element is strictly 2 points per element;
    a longer run is N-1 chained elements, not one multi-vertex polyline --
    confirmed empirically, see git history of this file)."""
    snapped = [tuple(snap(v) for v in pt) for pt in pts]
    for a, b in zip(snapped, snapped[1:]):
        WIRES.append([a, b])


def label(pos, text, dir="right"):
    justify = {"right": "left", "left": "right", "up": "left", "down": "left"}[dir]
    LABELS.append(dict(pos=(snap(pos[0]), snap(pos[1])), text=text, justify=justify))


def tap_label(ref, pin, text, dx, dy):
    """Short outward stub + label, directly at a component pin."""
    p0 = P(ref, pin)
    p1 = (p0[0] + dx, p0[1] + dy)
    wire(p0, p1)
    d = "right" if dx > 0 else "left" if dx < 0 else ("down" if dy > 0 else "up")
    label(p1, text, dir=d)


def bus(pts, taps=()):
    wire(*pts)
    for t in taps:
        JUNCTIONS.append((snap(t[0]), snap(t[1])))


def signal_through(mod_ref, mod_pin, via_ref, via_pin, text, extend, mod_stub=-2.54):
    """Module pin and pull-up/series-element pin both get their own short
    stub + matching signal label (no wire between them). The two
    components are still drawn right next to each other on the sheet for
    a clean visual pairing, but a real wire there proved unsafe: with this
    many pull-ups packed into one narrow corridor next to the module's
    2.54mm pin pitch, a resistor's own 7.62mm rail stub reliably ends up
    crossing a NEIGHBOURING signal's horizontal run (confirmed repeatedly
    via check_nets.py -- e.g. R13's +3V3 stub shorting into SD_CS once every
    pull-up was placed close enough to look tidy). Labels sidestep this
    entirely regardless of how tightly the resistors are packed."""
    tap_label(mod_ref, mod_pin, text, mod_stub, 0)
    d = "right" if extend[0] > 0 else "left" if extend[0] < 0 else ("down" if extend[1] > 0 else "up")
    p1 = P(via_ref, via_pin)
    p2 = (p1[0] + extend[0], p1[1] + extend[1])
    wire(p1, p2)
    label(p2, text, dir=d)


def nc(ref, pin):
    NO_CONNECTS.append(P(ref, pin))


STUB = 7.62  # outward stub length for label taps (rule 31: must clearly
             # exceed the ref/value text offset)

# ===========================================================================
# EN reset circuit -- tiny local cluster (module pin, R8, C9, C10, SW2 all
# within ~40mm, nothing else nearby): kept as one direct bus. R8/R9 use
# different X lanes so their +3V3 stubs (7.62mm) can't overlap each other.
# ===========================================================================
bus([P("U1", "3"), P("R8", "2"), P("C9", "2"), P("C10", "2"), P("SW2", "2")],
    taps=[P("R8", "2"), P("C9", "2"), P("C10", "2")])
tap_label("R8", "1", "+3V3", 0, -STUB)
tap_label("C9", "1", "GND", 0, -STUB)
tap_label("C10", "1", "GND", 0, -STUB)
tap_label("SW2", "1", "GND", -STUB, 0)

# ===========================================================================
# BOOT circuit
# ===========================================================================
bus([P("U1", "27"), P("R9", "2"), P("SW3", "2")], taps=[P("R9", "2")])
tap_label("R9", "1", "+3V3", 0, -STUB)
tap_label("SW3", "1", "GND", -STUB, 0)

# ===========================================================================
# I2C to the GPS Qwiic connector: direct wire module->pull-up (adjacent),
# then a signal label to reach J3 (74mm away, across the SPI cluster --
# exactly the "long distance" case for a label instead of a routed wire).
# ===========================================================================
# Adjacent module pins are only 2.54mm apart but label text is much wider
# than that, so each pin in a tightly-packed run gets a DIFFERENT stub
# length -- otherwise same-length labels on neighbouring pins visually
# overlap (confirmed by rendering an actual SVG/PDF and inspecting it,
# not just ERC, which doesn't care about text collisions at all).
signal_through("U1", "12", "R10", "2", "I2C_SDA", (-2.54, 0), mod_stub=-2.54)
signal_through("U1", "17", "R11", "2", "I2C_SCL", (-2.54, 0), mod_stub=-3.81)
tap_label("R10", "1", "+3V3", 0, -STUB)
tap_label("R11", "1", "+3V3", 0, -STUB)
tap_label("J3", "1", "GND", -STUB, 0)
tap_label("J3", "2", "+3V3", -STUB, 0)
tap_label("J3", "3", "I2C_SDA", STUB, 0)
tap_label("J3", "4", "I2C_SCL", STUB, 0)

# ===========================================================================
# SPI to the microSD socket: same pattern. J4's real pinout interleaves
# VDD/VSS between the signal pins, but that no longer matters -- every
# J4 pin gets its own short stub + matching signal label, no routed run
# has to reach across to the connector's (different) pin pitch at all.
# ===========================================================================
signal_through("U1", "18", "R12", "2", "SD_CS", (-2.54, 0), mod_stub=-2.54)
tap_label("R12", "1", "+3V3", 0, -STUB)
tap_label("U1", "19", "SD_MOSI", -11.43, 0)   # no pull-up needed
tap_label("U1", "20", "SD_SCK", -20.32, 0)
signal_through("U1", "21", "R13", "2", "SD_MISO", (-2.54, 0), mod_stub=-29.21)
tap_label("R13", "1", "+3V3", 0, -STUB)
signal_through("U1", "22", "R14", "2", "SD_CD", (-2.54, 0), mod_stub=-38.1)
tap_label("R14", "1", "+3V3", 0, -STUB)

# Pins 2-7 are six pins in a row, each only 2.54mm apart -- every one gets
# a longer stub than the last so none of the six labels land in the same
# column (same reasoning as U1's own pin stubs above).
tap_label("J4", "2", "SD_CS", -7.62, 0)
tap_label("J4", "3", "SD_MOSI", -16.51, 0)
tap_label("J4", "4", "+3V3", -25.4, 0)      # VDD
tap_label("J4", "5", "SD_SCK", -34.29, 0)
tap_label("J4", "6", "GND", -43.18, 0)      # VSS
tap_label("J4", "7", "SD_MISO", -52.07, 0)
tap_label("J4", "9", "GND", -7.62, 0)       # DET_B (other detect-switch leg)
tap_label("J4", "10", "SD_CD", -16.51, 0)
tap_label("J4", "SH", "GND", 0, STUB)       # shield tab
nc("J4", "1")   # DAT2 unused in SPI mode
nc("J4", "8")   # DAT1 unused in SPI mode

# ===========================================================================
# UART debug header -- module pins and header are both close by and share
# the header's own 2.54mm pitch, but they sit right above the crowded
# USB-C/battery/LDO cluster, so route via labels rather than a routed run
# through that territory.
# ===========================================================================
tap_label("U1", "37", "DBG_TXD0", STUB, 0)
# down+right (an L, not a diagonal): straight right runs into D1's VBUS stub.
_rxd0_p0 = P("U1", "36")
_rxd0_p1 = (_rxd0_p0[0] + STUB, _rxd0_p0[1])
_rxd0_p2 = (_rxd0_p1[0], _rxd0_p1[1] + 5.08)
wire(_rxd0_p0, _rxd0_p1, _rxd0_p2)
label(_rxd0_p2, "DBG_RXD0", dir="down")
tap_label("J5", "4", "DBG_TXD0", -STUB, 0)
# down+left (an L, not a diagonal): a longer straight-left reach runs into D1.
_j5rxd0_p0 = P("J5", "3")
_j5rxd0_p1 = (_j5rxd0_p0[0] - STUB, _j5rxd0_p0[1])
_j5rxd0_p2 = (_j5rxd0_p1[0], _j5rxd0_p1[1] + 5.08)
wire(_j5rxd0_p0, _j5rxd0_p1, _j5rxd0_p2)
label(_j5rxd0_p2, "DBG_RXD0", dir="down")
tap_label("J5", "2", "+3V3", STUB, 0)
tap_label("J5", "1", "GND", STUB, 0)

# ===========================================================================
# USB-C: D+/D- run through the USBLC6-2SC6 ESD array into the module. J1's
# A6/B6 (D+) and A7/B7 (D-) are physically duplicated pins on the same
# internal node (not pre-merged by the symbol) -- bridge each pair with a
# short direct jumper, then continue through D1 via labels (D1 sits right
# next to J1, but the module is far off to the left across the whole
# battery/charger cluster).
# ===========================================================================
wire(P("J1", "A6"), P("J1", "B6"))    # D+ bridge (both pins, same internal node)
wire(P("J1", "A7"), P("J1", "B7"))    # D- bridge
JUNCTIONS.append(P("J1", "A6"))
JUNCTIONS.append(P("J1", "A7"))

# J1 and D1 are ~80mm apart across the CC-pulldown/VBUS-decoupling area --
# a routed wire there would have to cross that whole cluster, so this is
# label-only (same reasoning as D1<->U1 below).
tap_label("J1", "A6", "USB_DP", STUB, 0)  # A6/A7 are 5.08mm apart -- fine as-is
wire(P("D1", "1"), P("D1", "6"))                              # duplicate I/O1 pin, same node
JUNCTIONS.append(P("D1", "1"))
tap_label("D1", "1", "USB_DP", -STUB, 0)  # D1.1/D1.3 (I/O1/I/O2) are 2.54mm apart

tap_label("J1", "A7", "USB_DM", STUB, 0)
wire(P("D1", "3"), P("D1", "4"))                              # duplicate I/O2 pin, same node
JUNCTIONS.append(P("D1", "3"))
tap_label("D1", "3", "USB_DM", -STUB - 12.7, 0)

tap_label("U1", "14", "USB_DP", STUB, 0)
tap_label("U1", "13", "USB_DM", STUB + 12.7, 0)

nc("J1", "A8")   # SBU1 -- not used (no USB-C alt-mode/accessory support)
nc("J1", "B8")   # SBU2
tap_label("D1", "5", "+VBUS", 0, -STUB)
tap_label("D1", "2", "GND", STUB, 0)

tap_label("J1", "A1", "GND", 0, STUB)
tap_label("J1", "SH", "GND", -STUB, 0)
tap_label("J1", "A4", "+VBUS", 0, -STUB)
wire(P("J1", "A5"), P("R1", "1"))     # CC1 pull-down, direct (adjacent parts)
wire(P("J1", "B5"), P("R2", "1"))     # CC2 pull-down, direct
tap_label("R1", "2", "GND", 0, STUB)
tap_label("R2", "2", "GND", 0, STUB)
tap_label("C1", "1", "+VBUS", 0, -STUB)
tap_label("C1", "2", "GND", 0, STUB)
tap_label("D4", "1", "+VBUS", 0, -STUB)   # cathode -> VBUS (unidirectional TVS, per kicad-happy UC-002)
tap_label("D4", "2", "GND", 0, STUB)      # anode -> GND

# ===========================================================================
# Battery + charger (MCP73831). Rails: +VBUS feeds the charger's VDD;
# +VBAT_RAW is the raw battery/charger-output node; +VBAT_SYS is the same
# node after the power switch, feeding the LDO -- so the system can be
# switched off while the battery keeps charging.
# ===========================================================================
# These short chains kept crossing OTHER local wires whichever way the
# elbow was ordered (confirmed via check_nets.py -- e.g. the STAT->LED
# run at LED-cathode height clipped the PROG resistor's own stub a few mm
# over). Same fix as the bus signals: label instead of routing through it.
tap_label("U2", "1", "CHG_STAT", STUB, 0)   # right, not up -- U2.3 (VBAT) shares this
                                             # X 5.08mm below and also stubs upward
tap_label("D2", "1", "CHG_STAT", -STUB, 0)
tap_label("D2", "2", "CHG_LED_A", STUB, 0)              # LED anode -> series R (label: D2 is
tap_label("R4", "1", "CHG_LED_A", 0, -STUB)             # horizontal, R4 vertical -- pins don't line up)
tap_label("R4", "2", "+VBUS", 0, STUB)                  # opposite direction from pin 1 (only
                                                         # 7.62mm apart -- same-direction stubs overlap)
tap_label("U2", "5", "CHG_PROG", 0, -STUB)  # up, not down -- avoids D2's CHG_LED_A stub row
tap_label("R3", "1", "CHG_PROG", 0, -STUB)
tap_label("R3", "2", "GND", 0, STUB)

tap_label("U2", "2", "GND", -STUB, 0)
tap_label("U2", "3", "+VBAT_RAW", 0, -STUB)
tap_label("U2", "4", "+VBUS", 0, STUB)
tap_label("C2", "1", "+VBUS", 0, -STUB)
tap_label("C2", "2", "GND", 0, STUB)
tap_label("C3", "1", "+VBAT_RAW", 0, -STUB)
tap_label("C3", "2", "GND", 0, STUB)
tap_label("J2", "1", "+VBAT_RAW", STUB, 0)
tap_label("J2", "2", "GND", STUB, 0)
tap_label("SW1", "1", "+VBAT_RAW", -STUB, 0)
tap_label("SW1", "2", "+VBAT_SYS", STUB, 0)

# ===========================================================================
# LDO regulation
# ===========================================================================
tap_label("U3", "1", "+VBAT_SYS", -STUB, 0)
tap_label("U3", "2", "GND", 0, STUB)
tap_label("U3", "3", "+VBAT_SYS", -STUB - 12.7, 0)   # EN tied to VIN (always enabled);
                                                      # VIN is 2.54mm above, same X -- stagger
nc("U3", "4")
tap_label("U3", "5", "+3V3", STUB, 0)
tap_label("C4", "1", "+VBAT_SYS", 0, -STUB)
tap_label("C4", "2", "GND", 0, STUB)
tap_label("C5", "1", "+3V3", 0, -STUB)
tap_label("C5", "2", "GND", 0, STUB)
tap_label("R5", "1", "+3V3", 0, -STUB)
tap_label("R5", "2", "PWR_LED_A", 0, STUB)              # series R -> LED anode (label: R5 is
tap_label("D3", "2", "PWR_LED_A", STUB, 0)              # vertical, D3 horizontal -- pins don't line up)
tap_label("D3", "1", "GND", 0, STUB)

# ===========================================================================
# Battery-sense divider. Midpoint (R6.2 == R7.1, same coordinate by
# construction) reaches the module via a genuinely long-distance label.
# ===========================================================================
tap_label("R6", "1", "+VBAT_SYS", 0, -STUB)
JUNCTIONS.append(P("R6", "2"))
wire(P("R6", "2"), P("C6", "1"))      # midpoint -> filter cap, direct
tap_label("R7", "2", "GND", 0, STUB)
tap_label("C6", "2", "GND", 0, STUB)
tap_label("R6", "2", "BATT_SENSE", STUB, 0)
tap_label("U1", "28", "BATT_SENSE", STUB, 0)

# ===========================================================================
# Module's own power pins + bulk/HF decoupling
# ===========================================================================
tap_label("U1", "2", "+3V3", 0, -STUB)
tap_label("U1", "1", "GND", 0, STUB)
tap_label("C7", "1", "+3V3", 0, -STUB)
tap_label("C7", "2", "GND", 0, STUB)
tap_label("C8", "1", "+3V3", 0, -STUB)
tap_label("C8", "2", "GND", 0, STUB)

# ===========================================================================
# No-connects: strapping pins left floating per datasheet default (Table
# 4-1: GPIO3 floating, GPIO45/46 weak pull-down = correct default for this
# non-PSRAM, 3.3V-VDD_SPI module -- see peripheral schematic, Fig. 9-1,
# which leaves these bare too), plus every other genuinely free GPIO
# (rule 32: kicad-cli ERC treats a bare bidirectional MCU pin as a real
# pin_not_connected error, not a silent non-issue).
# ===========================================================================
USED_U1_PINS = {"1", "2", "3", "27", "12", "17", "18", "19", "20", "21", "22",
                 "36", "37", "13", "14", "28", "40", "41"}
from libextract import get_pins as _get_pins
for num, name, ptype, lx, ly, ang in _get_pins("RF_Module.kicad_sym", "ESP32-S3-WROOM-1"):
    if num not in USED_U1_PINS:
        nc("U1", num)

# ===========================================================================
# PWR_FLAGs: only on rails that have NO power_out pin anywhere on their own
# net -- +3V3 (U3.VOUT) and +VBAT_RAW (U2.VBAT) already have one, and a
# redundant flag there trips "two power outputs connected" as an ERROR, not
# just a style nit (confirmed by kicad-cli). GND, +VBUS and +VBAT_SYS have
# no power_out pin at all and genuinely need the flag.
# ===========================================================================
for i, railname in enumerate(["GND", "+VBUS", "+VBAT_SYS"]):
    fx, fy = snap(60 + i * 25), snap(240)
    PWR_FLAGS.append((fx, fy))
    wire((fx, fy), (fx, fy - STUB))
    label((fx, fy - STUB), railname, dir="up")

if __name__ == "__main__":
    print(f"{len(WIRES)} wires, {len(LABELS)} labels, {len(NO_CONNECTS)} NC, "
          f"{len(JUNCTIONS)} junctions, {len(PWR_FLAGS)} pwr flags.")

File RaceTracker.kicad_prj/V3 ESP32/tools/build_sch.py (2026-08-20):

"""Generate the RaceTracker V3 (ESP32-S3) single-sheet schematic.

Runs standalone: writes a complete .kicad_sch to OUT_PATH. Re-run after any
edit to this file to regenerate from scratch (idempotent).
"""
import uuid
from libextract import get_flat_symbol, get_pins
from geom import pin_abs

PROJECT_NAME = "RaceTracker_v3"
OUT_PATH = ("/Users/jonaschramm/Desktop/RaceTracker_KiCad_v14/RaceTracker.kicad_prj/"
            "V3 ESP32/RaceTracker_v3/RaceTracker_v3.kicad_sch")

GRID = 1.27


def snap(v):
    return round(round(v / GRID) * GRID, 3)


def u():
    return str(uuid.uuid4())


# ---------------------------------------------------------------------------
# Part catalogue: part-type -> (lib file, symbol name, nickname, footprint)
# ---------------------------------------------------------------------------
PART_LIB = {
    "ESP32S3": dict(libfile="RF_Module.kicad_sym", sym="ESP32-S3-WROOM-1",
                     nickname="RF_Module", footprint="RF_Module:ESP32-S3-WROOM-1"),
    "USBC": dict(libfile="Connector.kicad_sym", sym="USB_C_Receptacle_USB2.0_16P",
                  nickname="Connector", footprint="Connector_USB:USB_C_Receptacle_HRO_TYPE-C-31-M-12"),
    "USBLC6": dict(libfile="Power_Protection.kicad_sym", sym="USBLC6-2SC6",
                    nickname="Power_Protection", footprint="Package_TO_SOT_SMD:SOT-23-6"),
    "TVS": dict(libfile="Diode.kicad_sym", sym="PESD5V0S1UL",
                 nickname="Diode", footprint="Diode_SMD:D_SOD-882"),
    "LDO": dict(libfile="Regulator_Linear.kicad_sym", sym="AP2112K-3.3",
                 nickname="Regulator_Linear", footprint="Package_TO_SOT_SMD:SOT-23-5"),
    "MCP73831": dict(libfile="Battery_Management.kicad_sym", sym="MCP73831-2-OT",
                       nickname="Battery_Management", footprint="Package_TO_SOT_SMD:SOT-23-5"),
    "SDCARD": dict(libfile="Connector.kicad_sym", sym="Micro_SD_Card_Det2",
                     nickname="Connector", footprint="Connector_Card:microSD_HC_Molex_104031-0811"),
    "CONN4": dict(libfile="Connector_Generic.kicad_sym", sym="Conn_01x04",
                    nickname="Connector_Generic", footprint=None),  # footprint set per-instance
    "CONN2": dict(libfile="Connector_Generic.kicad_sym", sym="Conn_01x02",
                    nickname="Connector_Generic", footprint=None),
    "R": dict(libfile="Device.kicad_sym", sym="R", nickname="Device",
               footprint="Resistor_SMD:R_0603_1608Metric"),
    "C": dict(libfile="Device.kicad_sym", sym="C", nickname="Device", footprint=None),
    "LED": dict(libfile="Device.kicad_sym", sym="LED", nickname="Device",
                 footprint="LED_SMD:LED_0603_1608Metric"),
    "SW_PUSH": dict(libfile="Switch.kicad_sym", sym="SW_Push", nickname="Switch",
                      footprint="Button_Switch_SMD:SW_SPST_B3U-1000P"),
    "SW_SPST": dict(libfile="Switch.kicad_sym", sym="SW_SPST", nickname="Switch",
                      footprint="Button_Switch_THT:SW_DIP_SPSTx01_Slide_6.7x4.1mm_W7.62mm_P2.54mm_LowProfile"),
    "PWR_FLAG": dict(libfile="power.kicad_sym", sym="PWR_FLAG", nickname="power", footprint=""),
}

R_FP = "Resistor_SMD:R_0603_1608Metric"
C_FP = "Capacitor_SMD:C_0603_1608Metric"
C_FP_BIG = "Capacitor_SMD:C_0805_2012Metric"

PWR_FLAG_BLOCK = '''\t(symbol "power:PWR_FLAG" (power) (pin_numbers hide) (pin_names (offset 0) hide) (in_bom no) (on_board no)
\t\t(property "Reference" "#FLG" (at 0 1.905 0) (effects (font (size 1.27 1.27)) hide))
\t\t(property "Value" "PWR_FLAG" (at 0 3.556 0) (effects (font (size 1.27 1.27))))
\t\t(property "Footprint" "" (at 0 0 0) (effects (font (size 1.27 1.27)) hide))
\t\t(property "Datasheet" "" (at 0 0 0) (effects (font (size 1.27 1.27)) hide))
\t\t(symbol "PWR_FLAG_0_0"
\t\t\t(pin power_out line (at 0 0 90) (length 2.54) hide
\t\t\t\t(name "pwr" (effects (font (size 1.27 1.27))))
\t\t\t\t(number "1" (effects (font (size 1.27 1.27))))
\t\t\t)
\t\t)
\t\t(symbol "PWR_FLAG_0_1"
\t\t\t(polyline (pts (xy 0 0) (xy 0 1.27) (xy -0.635 1.905) (xy 0 2.54) (xy 0.635 1.905) (xy 0 1.27))
\t\t\t\t(stroke (width 0) (type default)) (fill (type none))
\t\t\t)
\t\t)
\t)
'''

_pin_cache = {}


def part_pins(ptype):
    if ptype not in _pin_cache:
        info = PART_LIB[ptype]
        if info["libfile"] is None:
            _pin_cache[ptype] = [("1", "pwr", "power_out", 0.0, 0.0, 90)]
        else:
            _pin_cache[ptype] = get_pins(info["libfile"], info["sym"])
    return _pin_cache[ptype]


class Component:
    def __init__(self, ref, ptype, value, x, y, angle=0, footprint=None):
        self.ref = ref
        self.ptype = ptype
        self.value = value
        self.x, self.y, self.angle = x, y, angle
        self.footprint = footprint or PART_LIB[ptype]["footprint"]
        self.uuid = u()
        self.pin_uuid = {}

    @property
    def lib_id(self):
        info = PART_LIB[self.ptype]
        return f'{info["nickname"]}:{info["sym"]}'

    def pin_pos(self, number):
        for num, name, ptype, lx, ly, ang in part_pins(self.ptype):
            if num == number:
                return pin_abs(self.x, self.y, self.angle, lx, ly)
        raise KeyError(f"{self.ref}: no pin {number}")

    def pin_info(self, number):
        for num, name, ptype, lx, ly, ang in part_pins(self.ptype):
            if num == number:
                return name, ptype
        raise KeyError(f"{self.ref}: no pin {number}")


COMPONENTS = {}


def add(ref, ptype, value, x, y, angle=0, footprint=None):
    c = Component(ref, ptype, value, snap(x), snap(y), angle, footprint)
    COMPONENTS[ref] = c
    return c


# ---------------------------------------------------------------------------
# Placement
# ---------------------------------------------------------------------------
# ESP32-S3-WROOM-1 module: reference hub, pin math worked out on paper
# against the transform abs = f(inst, local) in geom.py.
U1 = add("U1", "ESP32S3", "ESP32-S3-WROOM-1-N8", 230, 150)

R_SPAN = 3.81  # Device:R and Device:C both have pins at local y = +-3.81


def y_of(ref, pin):
    return U1.pin_pos(pin)[1] if ref == "U1" else COMPONENTS[ref].pin_pos(pin)[1]


def vpart(ref, ptype, value, target_y, x, footprint=None):
    """Place a vertical 2-pin part (R/C) so its pin 2 (bottom) lands
    exactly on target_y -- pin 1 (top) ends up target_y - 2*R_SPAN away."""
    return add(ref, ptype, value, x, target_y - R_SPAN, angle=0, footprint=footprint)


EN_Y = y_of("U1", "3")     # EN
IO0_Y = y_of("U1", "27")   # BOOT
IO8_Y = y_of("U1", "12")   # I2C SDA
IO9_Y = y_of("U1", "17")   # I2C SCL
IO10_Y = y_of("U1", "18")  # SPI CS   (DAT3/CD)
IO11_Y = y_of("U1", "19")  # SPI MOSI (CMD)
IO12_Y = y_of("U1", "20")  # SPI SCK  (CLK)
IO13_Y = y_of("U1", "21")  # SPI MISO (DAT0)
IO14_Y = y_of("U1", "22")  # SD_CD
RXD0_Y = y_of("U1", "36")
TXD0_Y = y_of("U1", "37")
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

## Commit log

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2026-08-04 Zwei kritische Schaltplanfehler behoben
    Power.kicad_sch: Vertikale GND-Busleitung bei x=20.32 (y=41.91–59.69)
    entfernt, die J1.CC1 und J1.CC2 direkt auf GND kurzschloss. Die
    Pull-Down-Widerstände R37/R38 (5,1 kΩ) waren damit elektrisch wirkungslos.
    Ersetzt durch horizontale Verbindung (12.7, 41.91)→(20.32, 41.91) mit
    eigenem GND-Symbol (#PWR042) für J1.GND.
    Sensors_Storage.kicad_sch: Vertikale Leitung bei x=20.32 (y=50.8–77.47)
    entfernt, die U7.AD0, U7.INT, U7.FSYNC und U7.CLKIN auf GND kurzschloss
    und damit IMU_INT (PA10 des SAMD21) dauerhaft auf LOW zog. Ersetzt durch
    drei kurze Leitungen mit separaten GND-Symbolen (#PWR100, #PWR101).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
    [Power.kicad_sch, Sensors_Storage.kicad_sch]
2026-08-04 ERC auf 0/0: J1.CC2/R38, J7-Draht und PB1/R3 verbunden, VBUS-Cap ergänzt
    Echte KiCad-ERC (kicad-cli sch erc) fand 7 Verstöße, alle auf dasselbe
    Muster zurückgeführt: ein Bauteil-Pin lag exakt auf einem Draht, aber
    ohne Endpunkt-Treffer oder Junction erkannt daher KiCad ihn nicht als
    verbunden. Behoben durch Draht-Trimming auf die exakte Pin-Position,
    verifiziert per kicad-cli-Netzlisten-Diff (nur die betroffenen Pins
    ändern sich, sonst nichts an den 128 Bauteilen):
    - Power.kicad_sch: J1.CC2 <-> R38 (5,1k Pulldown) verbunden, gleicher
    Fehlertyp wie der CC1/GND-Kurzschluss aus dem letzten Commit, nur
    diesmal eine offene statt einer kurzgeschlossenen Verbindung
    - Power.kicad_sch: J7.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
    [MCU_Radio.kicad_sch, Power.kicad_sch]
2026-08-05 Referenzabgleich gegen MKR-WiFi-1010-Eagle-Schaltplan: 2 Abweichungen behoben
    Systematischer Netz-für-Netz-Vergleich zwischen der originalen Eagle-
    Referenz (MKRWiFi1010V2.0.sch) und der aktuellen KiCad-Netzliste ergab
    78 von 85 Netzen exakt identisch. Die restlichen 7 waren bis auf zwei
    reine Pin-Namens-/Nummerierungsunterschiede zwischen Eagle- und
    KiCad-Symbolen (Q5 Multi-Gate-Split, PB1-Kontaktnummerierung, J7/Q2
    Pin-Namen) — keine echten Fehler.
    Zwei echte Abweichungen behoben:
    - MCU_Radio.kicad_sch: Serienwiderstand R2 (39R) am Reset-Pin des
    SWD-Headers ergänzt. War beim Umbau von MKR-Debug-Header (J2,
    entfallen) auf den neuen SWD-Header (J12) verlorengegangen — SWCLK
    (R4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
    [MCU_Radio.kicad_sch, Power.kicad_sch]
2026-08-05 J1: echten USB-C-Steckverbinder statt Platzhalter eingebaut
    Ersetzt das custom RaceTracker:CONN_USB_C_UFP (8 abstrahierte Pins,
    Footprint-Platzhalter TBD_USBC_CONNECTOR) durch KiCads offizielles
    Connector_USB:USB_C_Receptacle_USB2.0_16P-Symbol (16 Pins, reales
    A/B-Pinout) mit passendem Footprint für einen konkreten, gut verfügbaren
    Steckverbinder:
    - MPN: TYPE-C-31-M-12 (Hroparts), LCSC C165948, 336k Stück verfügbar
    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
    [Power.kicad_sch]
2026-08-05 Footprints für Power+MCU_Radio: aus MKR1010-Eagle-Referenz importiert
    Nutzt kicad-cli pcb import, um die reale MKR-WiFi-1010-Platine
    (user-bereitgestellt, MKRWiFi1010V2.0.brd) nach KiCad zu konvertieren
    und daraus bewährte, aus einem tatsächlich gefertigten Board stammende
    Footprint-Geometrien zu extrahieren statt sie zu schätzen:
    - 15 spezielle Footprints neu in RaceTracker.pretty/ (SOT-143B für D1,
    SOD-323FL für D2/D3, SOT-523 für Q1/Q3, SON-8 für Q2, SOT-363 für Q5,
    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
    [MCU_Radio.kicad_sch, Power.kicad_sch]
2026-08-05 Footprints für GPS+Sensors_Storage: 132/132 Bauteile jetzt komplett
    GPS-Blatt: SMA_EDGE, ML414H_COIN_CELL und ZED_F9P_LGA102 (bereits
    vorhandene Custom-Footprints) verlinkt, Pad-Namen gegen Schaltplan-Pins
    verifiziert. Restliche Passiva auf Standardbibliothek gemappt.
    Sensors_Storage-Blatt: U7 (MPU-6050) auf KiCads eigene
    Sensor_Motion:InvenSense_QFN-24_4x4mm_P0.5mm (exakt für diesen Chip
    vorgesehen, nicht generisch geraten). J10 (MicroSD) auf
    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
    [GPS.kicad_sch, Sensors_Storage.kicad_sch]
2026-08-05 RaceTracker.kicad_pcb: erste Platzierung aller 130 Bauteile
    Neu erzeugt über KiCads pcbnew-Python-API (garantiert gültige
    Serialisierung statt handgeschriebener S-Expressions). Aufgeteilt in
    4 sequenzielle Zonen ohne Überlappung:
    1. MKR-abgeleitete Teile (Power+MCU_Radio, die in der Eagle-Referenz
    vorkommen): Original-Positionen/-Rotationen 1:1 übernommen
    2. Neue Power/MCU_Radio-Teile ohne Eagle-Vorbild (USB-C J1, C34, R2,
    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
    [RaceTracker.kicad_pcb]
2026-08-05 Sensors_Storage-Blatt gegen Datenblätter geprüft: C42 war 1000x zu groß
    Gegen das offizielle InvenSense MPU-6000/6050 Product Specification
    (Abschnitt 7.3, Bill of Materials for External Components) geprüft:
    - C42 (Ladungspumpen-Kondensator an CPOUT, Pin 20): war 2u2 (2,2µF),
    Datenblatt verlangt exakt 2,2nF — Faktor-1000-Fehler behoben.
    Falscher Wert hätte die interne Ladungspumpe (versorgt die
    MEMS-Gyroskop-Oszillatoren) vermutlich funktionsunfähig gemacht.
    - C41 (Regler-Filterkondensator an REGOUT, Pin 10, 100nF): korrekt,
    entspricht der Datenblattvorgabe von 0,1µF.
    - AD0 auf GND → I2C-Adresse 0x68, stimmt mit der Schaltplan-Beschriftung
    überein.
    - CLKIN/FSYNC auf G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
    [Sensors_Storage.kicad_sch]
2026-08-05 Routing: 93,8% automatisch via FreeRouting geroutet, Branding ergänzt
    Specctra-DSN-Export der platzierten Platine → FreeRouting (Open-Source-
    Autorouter, headless über kicad-cli/pcbnew-API-Pipeline) → SES-Re-Import.
    20 Durchläufe, 388 → 24 unverdrahtete Verbindungen (93,8% Autoroute-Quote).
    Verbleibende 24 sind größtenteils feinstufige QFN-Pins von U1 (SAMD21)
    und U2 (NINA-W102) — brauchen manuelles Fine-Pitch-Routing, für das ich
    ohne visuelle Kontrolle keine verlässliche automatische Lösung anbieten
    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
    [RaceTracker.kicad_pcb]
2026-08-05 D4: TVS-Diode für VBUS-ESD-Schutz an J1 ergänzt
    Löst die zuvor offen gelassene Bauteilfrage (UC-002 aus der
    kicad-happy-Analyse: kein ESD-Schutz auf der VBUS-Leitung, D1 deckt
    nur D+/D- ab).
    Nexperia PESD5V0S1BA (LCSC C5261083, SOD-323), unidirektionale 5V-TVS,
    166k Stück verfügbar. Kathode an USBC_VBUS, Anode an GND — klemmt
    Überspannungstransienten von VBUS nach Masse ab.
    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
    [Power.kicad_sch]
2026-08-05 PCB-Layout finalisiert: Edge-Connectoren, RF-Cluster restauriert, Routing 92,8%
    - USB-C (J1), MicroSD (J10) und GPS-Antenne (E101) bündig an derselben
    Gehäusekante platziert, korrekt nach außen orientiert (90°, empirisch
    gegen pcbnew's CW-Rotationskonvention verifiziert). Akku-Stecker (J7)
    bleibt bewusst im Gehäuseinneren.
    - GPS-RF-Cluster (E101/U103/FB101) nach versehentlicher manueller
    Verschiebung wieder auf die u-blox-Referenzabstände gebracht; Board
    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
    [RaceTracker.kicad_pcb]
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2026-08-11 v2-simple: vereinfachter Ein-Blatt-Schaltplan, nur Platzierung
    Neue, deutlich reduzierte Version (76 statt 131 Bauteile) für den Kern-
    anwendungsfall "GPS-Position mit maximaler Rate auf SD-Karte schreiben":
    ZED-F9P, NINA-W102, zweite 3V3D-Schiene und MPU-6050 entfallen; GPS/WiFi
    werden über neue externe 8-polige Stecker (J20/J22) angebunden, e-Paper
    (J21) bleibt als steckbarer Header.
    Alle Werte/Footprints/Pad-Namen stammen unveraendert aus den fertigen,
    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
    [RaceTracker_v2.kicad_sch]
2026-08-11 v2-simple: echte Eagle-Symbolgrafik statt selbstgezeichneter Symbole
    Alle MKR-referenz-abgeleiteten Bauteile (R/C/L/PTC-Passive, SAMD21, BQ24195L,
    AP2112K-3.3, ESD-Diode, SIA817, 2N7002, PTS820-Taster, Kristall, LiPo-JST,
    LED, Schottky-Diode) nutzen jetzt die per KiCad-Eagle-Import erzeugte
    Original-Grafik aus der Arduino-MKR-WiFi-1010-Referenz statt der bisherigen
    Generic-Symbole, auf Wunsch des Nutzers ("die sehen verschieden aus").
    Bibliothek dazu neu unter reference/eagle/ (gemeinsam nutzbare Referenz,
    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
    [RaceTracker_v2.kicad_sch]
2026-08-14 v2-simple: fehlende Schutz-/Pullup-Bauteile ergänzt (D4, C34, R2, R21, R43)
    Teileabgleich gegen v1 zeigte 5 echte Lücken unabhängig von der bewussten
    GPS/NINA/MPU-Reduktion: USB-VBUS-ESD-Schutz (D4) und -Entkopplung (C34) an
    J1, SWD-Reset-Schutzwiderstand (R2) an J12, OTG-Erkennungs-Pullup (R21) am
    Q3-Gate, SD-Card-Detect-Pullup (R43) an J10. Alle 5 existieren bereits
    ERC-geprüft in v1 und wurden über die bestehende extract_v1.py ->
    map_eagle_symbols.py -> gen_symbols_v2.py -> build_sheet_v2.py Pipeline neu
    gezogen (Werte/Footprints 1:1 aus v1, Eagle-Symbolgrafik erhalten). Keine
    Kollisionen, SVG-Export geprüft.
    [RaceTracker_v2.kicad_sch]
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2026-08-14 v2-simple: ERC auf 0 Fehler/0 Warnungen gebracht (Grid-Snap + Pin-Konfliktmatrix)
    Zwei getrennte Ursachen für die bisherigen 380 Warnungen behoben:
    1. endpoint_off_grid (371x): Bauteil-Ursprünge in build_sheet_v2.py kamen
    aus reiner Bounding-Box-Kumulation und lagen nie auf dem 1.27mm-Raster;
    eigene Stub-Länge (6.5mm) in wire_v2.py war ebenfalls kein Vielfaches
    davon. Beides jetzt auf das Raster gerundet (neue snap()-Funktion in
    beiden Skripten, STUB_LEN auf 6.35mm = 5×1.27mm korrigiert).
    2. pin_to_pin (9x, "Bidirectional and Power output are connected"): U5s
    (BQ24195L) VBUS/TH/PGND/SYS/BAT-Pins sind laut Symbol "Bidirectional"
    (im Datenblatt tatsächlich bidirektiona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
    [RaceTracker_v2.kicad_sch]
2026-08-19 V3: neues ESP32-S3-WROOM-1 Schaltplan-Projekt (USB-C, LiPo-Laden, microSD, Qwiic-GPS)
    Kompletter Pivot von SAMD21 (v2-simple) auf ESP32-S3-WROOM-1-N8 als neue
    Hauptplattform. Ein-Blatt-Schaltplan in RaceTracker.kicad_prj/V3 ESP32/,
    programmatisch erzeugt aus den echten KiCad-10-Systembibliotheken (kein
    Custom-Symbol) und der offiziellen Espressif-Referenzbeschaltung (Fig. 9-1).
    Enthalten:
    - ESP32-S3-WROOM-1-N8 mit EN-RC-Delay, Boot/Reset-Tastern, Entkopplung
    - USB-C mit CC-Pulldowns, USBLC6-2SC6 (D+/D-) und separater VBUS-TVS
    - MCP73831-Laderegler + AP2112K-3.3-LDO, Schalter trennt System vom Akku
    ohne das Laden zu unterbrechen
    - microSD (SPI) und Qwiic-GPS-Anschluss (I2C), je mit Pull-up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
    [New Version with WROOM.kicad_pcb, New Version with WROOM.kicad_sch]
2026-08-20 V3: PCB-Footprint-Platzierung (kein Routing) + Widerstand-Footprint-Fix
    - build_sch.py: generische "R" Bauteile hatten kein Footprint gesetzt
    (PART_LIB-Default war None) -- auf R_0603_1608Metric korrigiert.
    - Neue PCB unter RaceTracker.kicad_prj/V3 ESP32/New Version with WROOM/:
    70x97mm, alle 39 Footprints platziert via tools/build_pcb.py (pcbnew-
    Python-Scripting) + tools/layout.py (Shelf-Packer mit real gemessenen
    Courtyard-Bounding-Boxen aus tools/fp_bbox.py, nicht geschaetzt --
    der erste Versuch mit Wunschkoordinaten ergab 43 DRC-Fehler).
    U1 um 90 Grad gedreht, damit die im offiziellen Footprint bereits
    enthaltene Antennen-Keepout-Zone zum linken Rand zeigt statt die
    komp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
    [New Version with WROOM.kicad_pcb, New Version with WROOM.kicad_sch]
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2026-08-20 V3: C2 (MCP73831 VDD-Entkopplung) von 1uF auf 4.7uF korrigiert
    Datenblatt-Review aller Bauteile gegen die jeweilige typische Beschaltung
    (MCP73831, AP2112K-3.3, USBLC6-2SC6, PESD5V0S1UL real heruntergeladen und
    gegengeprueft). Einziger echter Fund: MCP73831 Abschnitt 3.1 verlangt am
    VDD-Pin explizit "Bypass to VSS with a minimum of 4.7 uF" -- C2 hatte nur
    1uF. VBAT-seitige Entkopplung (C3=4.7uF) stimmte bereits exakt. AP2112K-3.3
    (1uF/1uF), USBLC6-2SC6 (keine externen Bauteile noetig) und PESD5V0S1UL
    (Polaritaet K->VBUS, A->GND) bestaetigt korrekt.
    ERC 0/0, DRC 0 Fehler nach dem Fix weiterhin bestaetigt.
    [RaceTracker_v3.kicad_pcb, RaceTracker_v3.kicad_sch]
2026-08-22 V3 PCB: manuelle Platzierung des Nutzers uebernommen, 6 DRC-Fehler behoben
    Nutzer hat Bauteile in der KiCad-GUI manuell verschoben (deutlich
    kompakteres Layout als mein Original) und im alten "New Version with
    WROOM"-Pfad gespeichert (KiCad hatte die Datei wohl noch von vor der
    Umbenennung offen). Fehler wurden dort chirurgisch behoben (pcbnew
    LoadBoard + gezielte Korrektur, nicht neu generiert -- bewahrt die
    manuelle Platzierung vollstaendig):
    - copper_edge_clearance: R14-Pad war 0.45mm statt min. 0.5mm vom
    Rand entfernt -- Bauteil um 0.15mm verschoben.
    - 4x Silkscreen-Warnungen (J1/D2/SW1-Referenzfeld ueberlappte mit
    Board-Rand, U1-Referenzfeld oder U1-Pads) -- nur die Textfelder neu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
    [RaceTracker_v3.kicad_pcb]
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2026-08-29 V3: 4 ERC-Fehler nach manueller Schaltplan-Bearbeitung behoben
    R14/R13/SW3 Pin 2 lagen jeweils in der Mitte eines durchgehenden Wire-
    Segments statt an dessen Endpunkt -- KiCad verbindet Pins nur an
    Wire-Endpunkten, nicht an Kreuzungspunkten mitten im Segment. Fix:
    Wire an der Pin-Koordinate in zwei Segmente gesplittet + Junction
    gesetzt.
    D3 (Power-LED) war an beiden Pins in denselben Knoten verdrahtet,
    wodurch GND und PWR_LED_A kurzgeschlossen wurden. Fix: D3 Pin 1
    (Kathode) direkt zum GND-Label umverdrahtet, getrennt vom
    PWR_LED_A-Knoten an Pin 2.
    ERC: 0 Fehler, 0 Warnungen. DRC (PCB, ungeroutet) weiterhin 0
    Violations -- Platzierung des Nutzers unverändert.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
    [RaceTracker_v3.kicad_sch]
2026-08-30 V3: 5 ERC-Warnungen nach Aufraeumen des Schaltplans behoben
    Beim Verschieben von J5 (UART-Debug-Header) naeher an U1 wurden dessen
    Pins 3/4 (DBG_RXD0/DBG_TXD0) versehentlich an einen neuen, dabei
    entstandenen +VBUS-Zweig angeschlossen statt an ihre eigenen Labels --
    +VBUS, DBG_RXD0 und DBG_TXD0 landeten dadurch auf einem gemeinsamen
    Netz (U1 TXD0/RXD0 beide pin_to_pin mit dem +VBUS PWR_FLAG verbunden).
    Fix: den kompletten neu entstandenen Verbindungszweig entfernt, J5 Pin
    3/4 je ein eigenes Label direkt am Pin gegeben (kein Stub, siehe Regel
    6), zwei dadurch verwaiste Alt-Labels entfernt.
    Zusaetzlich 2 ueberstehende Wire-Enden (D2/CHG_LED_A, U2/CHG_STAT --
    Wire reichte 1.27-2.54mm ueber das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
    [RaceTracker_v3.kicad_sch]
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2026-09-08 V3: GND/+3V3-Ebenen + Power-Rails neu geroutet (Layer-Bug gefixt)
    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
    [RaceTracker_v3.kicad_pcb]
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2026-09-17 V3: alle DRC-Errors und Silk-Warnungen behoben (0/0)
    Nach dem manuellen Routing des Users durch den User:
    Elektrische Fehler (kicad-cli DRC: 67 Violations, 14 offene Verbindungen -> 0/0):
    - Kurzschluss BATT_SENSE/GND behoben: Track um GND-Stitching-Via (78.0,66.5)
    herum verlegt, Via selbst nach (78.6,66.63) verschoben + Steg zu C6.2 ergaenzt
    (Pad U1.28 lag zu nah am urspruenglichen Via-Standort)
    - 21 redundante/doppelte/schwebende Vias entfernt (10 exakte Duplikate,
    3 ueberfluessig neben PTH-Pads, 6 nutzlos auf SMD-Pads ohne Lagenwechsel,
    2 komplett freischwebend)
    - 14 offene Verbindungen geschlossen: 10 verwaiste Plane-Stitching-Vias per
    kurzem Steg ans Ziel-Pad angebunden, 2 U4-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
    [RaceTracker_v3.kicad_pcb]
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2026-09-18 V3: Schematic-Parity-Luecken geschlossen, C8 platziert
    - Alle 44 Footprint-FPIDs auf den vollen Bibliothekspfad aus dem
    Schaltplan korrigiert (waren systemweit ohne Lib-Nickname
    gespeichert, z.B. "C_0603_1608Metric" statt
    "Capacitor_SMD:C_0603_1608Metric")
    - C2 Value-Feld 1uF -> 4.7uF (Schaltplan-Wert uebernommen, VBUS-Bulk-
    Cap an J1)
    - U4 Datasheet- + Description-Feld aus dem Schaltplan uebernommen
    - C8 (100nF, /+3V3-/GND) platziert bei (58.0,52.025)mm, F.Cu, 90 Grad
    - fehlte komplett auf der PCB, ist die fehlende HF-Entkopplung
    direkt an U1-Pin2 (3V3), analog zu C11/C12 bei U4
    - Netze zugewiesen (Ratsnest), NICHT geroutet (User routet selbst)
    Verifiziert: kicad-cli pcb dr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
    [RaceTracker_v3.kicad_pcb]
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2026-09-18 V3: redundante Vias auf J3s PTH-Pads entfernt
    J3 (PTH-Pinheader) verbindet ueber die Pad-Bohrung schon alle Kupferlagen
    inkl. GND-/+3V3-Ebene - zwei Stitching-Vias saßen exakt auf den Pad-Loechern
    (pin1/pin2), doppelte Bohrung an derselben Stelle, DRC holes_co_located.
    Entfernt, analog zum gleichen Fund bei DBG_TXD0/EPD_RST vorhin.
    Verifiziert: kicad-cli pcb drc --severity-all -> 0 Errors (nur die 5
    erwarteten lib_footprint_mismatch-Warnings), 0 offene Verbindungen
    (User hat das Routing inzwischen fertiggestellt). ERC weiterhin 0/0.
    [RaceTracker_v3.kicad_pcb]
2026-09-18 V3: weisse Platine + Racetracker-Logo auf der Rueckseite
    - Stackup-Farben gesetzt: F.Mask/B.Mask auf Weiss, F.SilkS/B.SilkS auf
    Schwarz (Standard-Kombination fuer weisse Platinen, sonst waere der
    Aufdruck unsichtbar). Das ist eine 3D-Vorschau-Einstellung im
    KiCad-File - die tatsaechliche Farbe wird zusaetzlich beim Fertiger
    (z.B. JLCPCB) im Bestellformular ausgewaehlt.
    - Racetracker-Wortmarke als Vektor-Silk auf B.SilkS platziert, zentriert,
    48mm breit (Board ist 56.2mm breit). Bild per potrace (GeoJSON-Backend)
    in 11 Buchstaben-Polygone mit korrekten Loechern (a/e-Punzen) verwandelt,
    dann in echte PCB_SHAPE-Polygone umgerechnet.
    - Bug gefunden und korrigiert: Rueckseiten-Grafi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
    [RaceTracker_v3.kicad_pcb]
2026-09-18 V3: Logo in freie Zone verschoben, MH-Labels symmetrisch
    - Racetracker-Logo: falsche Skalierungsbasis korrigiert (Bild hat viel
    weissen Rand, Skalierung bezog sich faelschlich auf die volle
    Bild-Leinwand statt auf die tatsaechliche Tinten-Flaeche - Logo kam
    dadurch erst viel kleiner raus als beabsichtigt). Neu mit korrekter
    Tinten-Bbox skaliert (44mm breit) und in die praktisch leere obere
    Haelfte der Rueckseite verschoben (dort liegt auf der Vorderseite nur
    U1 - der Bereich darunter ist auf der Rueckseite fast unbestueckt).
    Dadurch faellen alle 24 logo-bedingten Silk-Warnings weg.
    - Groessen-Fallstrick gefixt: bei dieser Y-Position ist die Platine nur
    49.05mm breit (der Gera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
    [RaceTracker_v3.kicad_pcb]
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2026-09-18 V3: MPN/Manufacturer/LCSC-Felder auf die PCB-Footprints synchronisiert
    Die MPN/Manufacturer/LCSC-Werte waren vor einigen Commits nur in den
    Schaltplan-Symbolen gesetzt worden, nie auf die PCB-Footprints uebertragen
    (braucht einen extra Sync-Schritt, entspricht "Update PCB from Schematic").
    Das erzeugte 45 footprint_symbol_field_mismatch-Warnings im Schematic-
    Parity-Check.
    Beim ersten Sync-Versuch legte pcbnew.FOOTPRINT.SetField() die neuen
    Felder als SICHTBAREN Silk-Text an gleicher Default-Position an -> 522
    neue DRC-Verstoesse (massive Silk-Ueberlappung ueber die ganze Platine).
    Korrigiert: Felder werden wie Datasheet/Description auf unsichtbar
    gesetzt (reine Metadaten, kein Aufdruck).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
    [RaceTracker_v3.kicad_pcb]
2026-09-18 V3: Logo-Spiegelung auf B.SilkS korrigiert
    potrace's GeoJSON-Backend gibt Y-invertierte Koordinaten aus (Y-up statt
    Bild-Y-down). Dadurch war das Racetracker-Logo auf der Rueckseite bisher
    spiegelverkehrt/unleserlich. Fix: Y-Korrektur (max_y - y_raw) vor dem
    X-Spiegel fuer die physische Rueckansicht.
    [RaceTracker_v3.kicad_pcb]
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
